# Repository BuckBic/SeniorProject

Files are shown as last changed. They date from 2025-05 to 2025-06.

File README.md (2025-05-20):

# Senior Project

# 🎓 Senior Project – Group 4

Welcome to the public repository for **Senior Project – Group 4**. This repo contains all project materials, including code, documentation, design files, and research resources. It serves as a centralized hub for development, collaboration, and public reference.

---

## 👥 Team Members

- Jeff  
- Josh  
- Valentin  
- Sean  

---

## 📁 Folder Structure

- `Documents/` – Reports, outlines, presentations, and written materials  
- `Code/` – Source code, testing scripts, and firmware  
- `Design/` – CAD models, schematics, wiring diagrams  
- `Resources/` – Data sheets, research materials, references

Folder structure may expand as the project evolves.

---

## 🎯 Purpose

- Share our work publicly for transparency and feedback  
- Collaborate as a team with version control and backups  
- Document progress across all project phases  
- Showcase our engineering and development process

---

## ✅ Usage Guidelines

- Use clear file names and keep folders organized  
- Commit regularly with concise messages  
- Don’t remove or overwrite other team members’ work without agreement  
- Keep content appropriate for public visibility

---

## 🌐 Public Access Notice

This repository is **public**. Anyone can view the content. Sensitive information or files not intended for public release should not be uploaded.

---

## 📌 Notes

If you're a reviewer, instructor, or visitor:  
All project content is located in the folders above. For questions or feedback, feel free to contact any team member directly.

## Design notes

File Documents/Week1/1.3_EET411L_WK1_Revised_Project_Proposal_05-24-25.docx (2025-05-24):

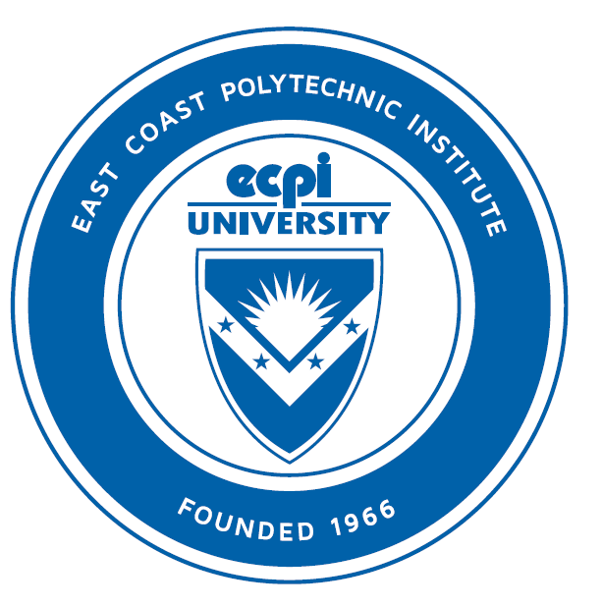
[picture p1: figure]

EET411

Senior Project

Instructor: Dr. Satinder Gill

Project Title: The Smart Bird Feeder

Team Members:

- Jeffery Wheeler: Project Lead
- Sean Copple: Team Member
- Joshua Tilson: Team Member
- Valentin Wolf: Team Member

Honor Pledge:

I pledge to support the Honor System of ECPI. I will refrain from any form of academic dishonesty or deception, such as cheating or plagiarism. I am aware that as a member of the academic community, it is my responsibility to turn in all suspected violators of the honor code. I understand that any failure on my part to support the Honor System will be turned over to a Judicial Review Board for determination. I will report to the Judicial Review Board hearing if summoned.

Date: 5/11/2025

# Abstract

This project focuses on the design and development of a smart bird feeder that improves upon existing feeders by addressing a common issue: unwanted access by animals such as raccoons. The main objective is to create a bird feeder that limits food access to birds only, using a controllable cover mechanism. The initial approach involves opening and closing the feeder based on day and night cycles. Future improvements include the integration of a load cell to detect the weight of visitors and deny access if the detected weight exceeds that of a typical bird, helping to distinguish between birds and other animals. To prevent from intruders of birds getting hurt, safety sensors are installed. The food will be supplied in small portions using a feeding wheel that is controlled by a servo motor. This mechanism ensures that the food always stays fresh.

Additional features planned include a camera for capturing images of feeding birds, a food level sensor to monitor and report when the food supply is low, and a solar panel with automatic sun tracking to power the device independently. The camera and load cell may also support bird identification and behavior analysis. The system will eventually be connected to a mobile app for live updates and alerts. The project uses a mix of sensors, automation, and app integration to enhance usability, sustainability, and data collection.

# Introduction

Bird feeding is a popular hobby that allows people to connect with nature, observe wildlife, and support local bird populations. However, many bird feeders on the market face a common problem: they are easily accessed by animals such as raccoons, squirrels, or larger pests that consume the bird food and often damage the feeder. This not only increases the cost of feeding birds but also limits the effectiveness and enjoyment of bird watching.

The main problem this project addresses is the lack of secure access control in traditional bird feeders. In many areas, especially near wooded or rural locations, raccoons and other animals frequently disrupt feeders. These intrusions reduce food availability for birds and can lead to frequent refilling and repair. While some commercial feeders offer partial solutions like baffles or weight-triggered perches, they are often not customizable, lack automation, and provide limited feedback to the user.

This project aims to design a smart bird feeder that not only prevents access by unwanted animals but also adds modern features such as automation, remote monitoring, and solar charging. By combining hardware like servo-controlled covers, load cells for weight detection, cameras, and level sensors, the feeder can intelligently respond to its environment. A mobile app will allow users to view bird photos, receive alerts about low food levels, and monitor feeder activity.

The goal of this project is to build a functional prototype of a smart bird feeder that solves the problem of animal intrusion while offering additional features to enhance the bird feeding experience. The project also explores ways to make the system energy-efficient and autonomous by incorporating solar power. Through this work, the team hopes to provide an innovative, practical solution for bird lovers and hobbyists.

# System Design

Block Diagram Overview

Power Input:

- The system is powered by a 5V 500mA solar cell.
- It collects energy from the sun to charge the batteries and run the system.

Power Management:

- The 5V relay protects the circuit and manages the power flow.
- The TP4056 charging module charges two 18650 lithium-ion batteries while allowing load sharing to avoid system shutdown during charging.
- The MT3608 boost converter steps up the battery voltage to a stable 5V output.
- A cooling system will be included to help manage heat from the charging process.

System Controller:

- A Raspberry Pi Zero is used to control the entire system.
- It processes sensor data, controls motors and LEDs, and handles any wireless communication or image capture if the camera is installed.

Field Devices:

- Servos:
  - 28BYJ-48 stepper motor rotates the bird feeder container.
  - SG90 micro servos are used for the food protection gate and solar tracking on two axes.
- Sensors:
  - Four photocell resistors detect ambient light for solar tracking and day/night detection.
  - A 1–20kg load cell with an amplifier monitors bird weight to determine if an animal is too heavy.
  - A photoresistor or IR sensor setup is used to detect when the food level is low.
- Optional Camera and Wireless Module:
  - The ESP32-CAM module adds the ability to take pictures of birds and send data wirelessly.
- RGB Status LED:
  - Used to show system status like low battery, low food, or normal operation.

Key Design Decisions and Considerations

- Solar Power: The use of a solar panel combined with load-sharing circuitry ensures that the bird feeder can operate independently of any external power sources.
- Energy Efficiency: The system limits power use at night by turning off non-essential devices like the camera and solar trackers when sunlight is not available.
- Animal Detection: The load cell allows the system to distinguish between birds and larger animals like raccoons, helping to protect the bird food.
- Weather Protection: All electronics are housed in a custom-printed, weatherproof enclosure to withstand outdoor conditions.
- Expandability: The design allows for future upgrades, such as sending bird photos through Wi-Fi or Bluetooth using the ESP32-CAM.

Block Diagram 1

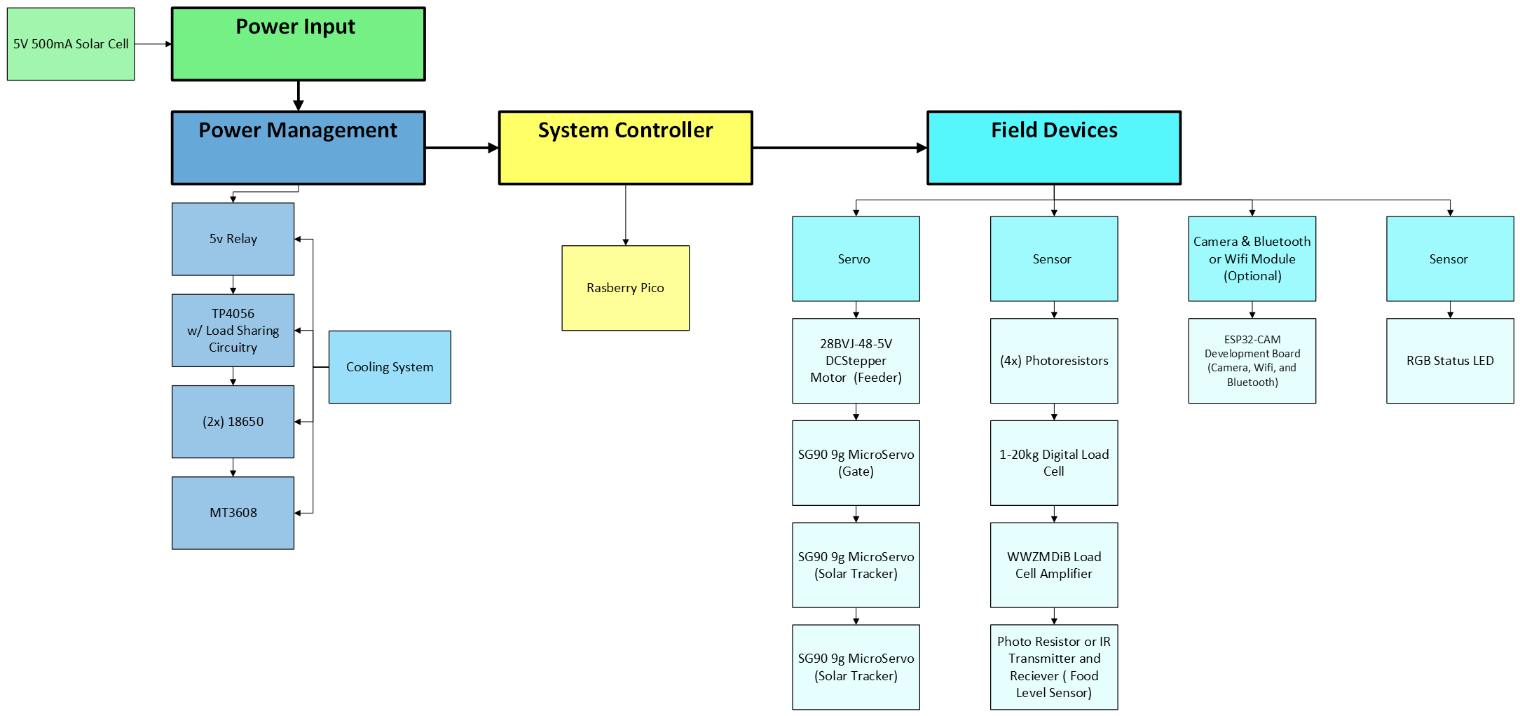
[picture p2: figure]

## Hardware Description

The smart bird feeder project uses a combination of commercially available hardware and custom-designed parts to achieve its goals. Each component was selected based on performance, availability, and compatibility with the system requirements.

Microcontrollers

- Raspberry Pi Zero The Raspberry Pi Zero is the main system controller. It manages data from the sensors, controls the field devices, and handles communication tasks such as Wi-Fi and Bluetooth.
  - Specifications: 1GHz single-core CPU, 512MB RAM, Wi-Fi, Bluetooth, mini HDMI, micro USB ports.
  - Selection Justification: Chosen for its compact size, low power consumption, and ability to handle more complex processing tasks like camera image handling and wireless communication. The Raspberry Pi Zero uses Python programming language which will be more suitable for more complex tasks.

Sensors

- Photoresistors Four photocell resistors are used to detect ambient light. They help determine day/night conditions for opening or closing the feeder and support solar tracking.
  - Selection Justification: Simple, low-cost, and reliable for detecting light changes.
- Load Cell with Amplifier (1–20kg range + HX711 amplifier) The load cell measures the weight of birds or animals at the feeder. It is sensitive enough to differentiate between birds and larger unwanted animals.
  - Selection Justification: Wide measurement range with good resolution. The amplifier boosts the small signal from the load cell to a readable level for the microcontrollers.
- Infrared Transmitter and Receiver / Photocell Food Sensor This sensor setup detects when the food level drops below a certain threshold inside the feeder.
  - Selection Justification: Simple solution to monitor food levels without requiring complex electronics.

Actuators

- SG90 9g Micro Servo Motors (4 units) Used for various mechanical movements:
  - One for rotating the food container.
  - One for opening and closing the food protection gate.
  - Two for tracking the solar panel in two axes (horizontal and vertical).
  - Specifications: 4.8V–6V operating voltage
  - Selection Justification: Lightweight, affordable, and widely supported by Arduino and Raspberry Pi libraries.
- 28BYJ-48 Stepper Motor with ULN2003 Driver Considered for smooth and accurate rotational control of the feeder.

Other Hardware Components

- 5V 500mA Solar Panel Provides renewable energy for battery charging, ensuring off-grid operation.
- TP4056 Charging Module with Load Sharing Circuit Manages safe charging of the batteries while allowing the system to continue running during charge cycles.
- 18650 Lithium-Ion Batteries (2 units) Store energy collected from the solar panel. Connected in parallel for longer runtime with 5000mAh combined capacity.
- MT3608 Boost Converter Increases the battery voltage up to 5V needed by most components.
- RGB Status LED Used to visually indicate different system statuses, such as food low, battery low, or normal operation.
- ESP32-CAM Module

Adds a camera, Wi-Fi, and Bluetooth capabilities to the system.

Custom-Designed Hardware Elements

- Feeder Mechanism: A rotating food container divided into four pockets, dispensing food every 90 degrees of rotation.
- Custom Base: Designed to securely hold all circuit boards and field devices inside a weatherproof enclosure.
- Solar Tracker Mount: A mechanical base built to allow the solar panel to rotate and track the sun for better charging efficiency.
- Load Cell Mounting Structure: Custom mounting for the load cell to ensure accurate and protected weight measurements.
- Bird Perch and Food Access Door: A landing perch for birds and a servo-controlled door that opens or closes to allow access to food based on sensor inputs.
- Acrylic Food Container: A tube that stores the bird food and makes it easy to check food levels visually.

## Software Description

The software for the smart bird feeder is still being developed. Right now, the goal is to create a simple program that controls the motors, sensors, and lights based on sensor readings.

The software will have three basic parts:

- Setup: Turn on and prepare all the parts like sensors, servos, and lights.
- Main Loop: Keep checking the sensors and make the feeder open or close based on the readings.
- Power Saving: Turn off parts of the system at night to save battery power.

Functions the Software Will Perform

- Open the food cover when it is daytime.
- Close the food cover when it is dark or when a heavy animal is detected.
- Turn on a light if food is running low.
- Move the solar panel to follow the sun (solar tracker).
- (Later) Take pictures of birds and send them over Wi-Fi.

Libraries and Tools Used

- PyCharm and micro python IDE for writing and loading the programs.
- Servo Library for moving the servo motors.
- ESP32-CAM Library (later) for taking pictures and sending them.

# Implementation & Testing

The implementation process for the smart bird feeder project started with designing and preparing the mechanical and electrical systems separately. This helped make sure that each part would fit and work correctly before full assembly.

System assembly and hardware integration

The mechanical structure of the bird feeder is being designed to be fully 3D printed. Special attention was given to leave enough space for all electrical components, as well as any future upgrades. Once the mechanical parts are finished, they are tested without any electronics installed to make sure everything fits and moves correctly. After the mechanical testing is complete, the electrical components like the Raspberry Pi, servos, sensors, and solar panel will be installed. The system will be assembled carefully to protect the wiring and to make sure that all parts are easy to access if repairs or upgrades are needed later.

Software development and debugging

The software development is done using simulation tools. Because many of the components were not available in Tinkercad, Wokwi was used to model and test the system. Debugging will continue as real components are installed, with special focus on testing the servo movements, sensor readings, and communication between parts.

Testing procedures and verification methods

Different parts of the system will be tested individually first:

- Solar Cells: Tested outside during daylight to check charging performance.
- Photosensors (Light Sensors): Tested outside to verify they correctly detect day and night conditions.
- Load Cell: Will be tested by placing different weights to make sure the readings match expected values.
- Food Level Sensor: Will be tested by adjusting food levels and checking if the sensor triggers correctly.
- Servos: Movements will be tested manually to ensure they open and close the gate properly and rotate the solar panel.
- Food dispenser will be tested first without and then with use of the stepper motor.

Once each part is tested, the full system will be tested as a whole, simulating real use by placing weights, blocking light, and adjusting food levels.

Challenges and implemented solutions

One challenge was designing the mechanical structure to fit all components while still keeping the feeder small and good-looking. Careful planning of the 3D-printed parts and early mechanical testing helped solve this issue. Another challenge was the limitation of only having three analog inputs. Temperature could also become a concern. Different 3D printing materials and colors are considered because some materials may warp or weaken in outdoor heat. Furthermore, it will be important to choose a printing material that is environmentally friendly and not harmful to the birds or other animals.

## Construction

The construction process for the smart bird feeder focuses on building strong mechanical parts, preparing for electrical integration, and testing subsystems before final assembly.

Fabrication Methods and Materials Used

Most of the mechanical components for the feeder are 3D printed. Using 3D printing allows the team to quickly create parts, test different designs, and adjust as needed.

Prototyping and Final Product Construction Process

Multiple mechanical prototypes are being made to make sure all electrical components fit properly. Since the final list of electronic parts might change, the design allows extra space for possible future upgrades.

The team divided the system into smaller sections to make testing easier. Subsystems like the solar tracker, food dispensing gate, and load cell assembly are built and tested separately. Once each subsystem works correctly, they will all be combined into one complete system.

Calibration and Fine-Tuning Steps

After assembling the full system, calibration and fine-tuning will be done. The servos will be adjusted to make sure they open and close the gates correctly. The load cell will be calibrated to measure bird weights accurately. Sensor thresholds, such as light levels for opening the gate, will be adjusted based on real outdoor testing. Software fine-tuning will also happen after full system assembly to make sure that all parts work together smoothly.

## Testing Process

The testing process for the smart bird feeder project includes a variety of tests to make sure that all functions work correctly, and that the system can survive outdoor conditions. Testing is being done step-by-step as the project is developed and assembled.

Comprehensive Testing Process

Testing is being performed on both mechanical and electrical systems. The motors, sensors, and software are tested to make sure they respond properly to different conditions. 3D printed parts are tested for correct fit, durability, and weather resistance. Electrical testing includes checking that the power system supplies enough energy and that sensor data is accurate.

Mechanical movements, waterproofing, and cooling of the electronics are also part of the testing process. The system is tested first in small parts and then as a complete unit once everything is installed.

Test Cases

Test Case 1: CAD Design and 3D Printing Test

Parts are tested after printing to make sure everything fits correctly without interference.

Test Case 2: Virtual Testing with WOKWI

Component connections and code are tested virtually using WOKWI to find problems early before installing real hardware.

Test Case 3: Hands-on Component Testing

Real components are wired together and tested using a multimeter, checking sensor readings and making sure motors move correctly.

Test Case 4: Overtemperature Prevention

The system is tested by varying the temperature around it to check if the cooling system, including fans and thermistors, keeps the electronics from overheating.

Test Case 5: Water Resistance Test

The case is sprayed with water while using water test strips inside to check for any leaks.

Test Case 6: Material Sunlight Resistance

Different 3D printed materials are exposed to sunlight to see how well they resist warping or becoming brittle.

Test Case 7: Weather Condition Testing

The feeder is tested under simulated heavy rain and wind conditions to check stability and water resistance.

Test Case 8: Environmental Material Testing

Different materials are tested to find out which ones last the longest in outdoor conditions while being environmentally friendly.

# Data Interpretation & Analysis

- Present and analyze the data collected during testing and project operation.
  - The data collected during the testing phases included values such as the overall mechanical measurements and how things would fit together after 3D printing, as well as circuit component compatibility and their operations defined by the code in microPython. Most components were originally based on one thing like the size of the pico and how many ports it had along with the power requirements. This lead to what kind of motors to use, the batteries, solar cell size and the relay for it, how much light triggers detection, and what weight to sense for a certain bird.
  - Raw Data:
    - Project Size: 4 inches Wide x 2 feet Tall
    - Bird Weight: 600 grams
    - Light Detection from ADC: 800
    - System Power requirements: 5V, 2 Amps
    - Charging requirements: 5V, 600 milliamps
    - Motor uses: Uln2003 driver, stepper, and 3x, 9-gram servos
    - IR Sensor Distance: 0.5 inches
- Discuss the meaning and implications of the obtained results.
  - Due to some of the results in the initial design, parts had to be redesigned in CAD to make sure they fit correctly and fixed some of the issues that occurred like the feeder bowl shape, component placement, and mechanical joints for both the lid and solar tracker. In addition, the Raspberry Pico only contained 3 analog to digital converters which forced us to use a digital light detecting resistor rather than simply using a photoresistor. This occurred again when trying to use the servo to rotate 360 degrees, because it can only move 180 degrees, meaning the uln2003 had to be implemented to work with the Raspberry Pico, driver a stepper motor. Lastly, the TP4056 charger would trigger overcurrent protection through its outputs, requiring the MT3608 to be connected directly to the lithium-ion batteries instead of through the charger’s output.
- Compare your results with theoretical expectations and existing research.
  - We expected not to get the results we were looking for in the first trials because it is difficult to do so on the first try. So constant adaptations of the project slowly developed though the month, resulting in major changes while maintaining the original idea. Online there are research documents on building similar products, however they do not fully imitate the work we wanted to do. Other feeders dispense food or have a camera, but do not offer solar rechargeability, food protection, or AI imaging assistance. Fewer others even used a Raspberry Pico on such a small scale so much of the final collected data like the physical measurements, working circuit, and code was done overtime as we figured out what worked and what didn’t.

# Conclusion

- Summarize the key findings and achievements of your project.
  - Few parts needed to be modified to work well with each other such as the physical dimensions, circuit connections, and code requirements.
  - Product size is needed to withstand the bird, other animals, contain components, and actuate without resistance.
  - Sensors must be within researched values like bird weight, light intensity, detection distances, and power requirements.
  - Power system needed to charge and discharge at proper voltages and current while also having a long working life.
- Restate the project objectives and evaluate their fulfillment.
  - The project objectives are to have a bird feeder that can dispense food to the correct bird based on weight, during the day only. It will be able to connect to Wi-Fi, track the sun, detect bird species, and sense when the bowl or the storage container is empty.
- Discuss the overall success of your project and its limitations.
  - Currently we have been very successful in creating a working product, however it is not assembled yet and still requires three more components to be implemented before its completion. The limitation for this system is feeding crows and keeping out other scavengers. With small changes in the design though, it can be used to feed other animals, charge a larger battery with MPPT, or be utilized in a factory to dispense other materials while keeping track of specific variables.

# Future Work

At this stage, the overall design remains consistent with our original plan, and that’s intentional. We’re now fully engaged in the build phase, installing components, testing circuits, and verifying mechanical movements. Tasks include wiring the load cell and stepper motor, calibrating sensor inputs, and confirming servo behavior in real-world conditions. We’ve also started 3D printing parts for the enclosure and feeder mechanism, refining each iteration for better fit and function.

On the software side, we’re moving from simulations to hardware testing. The control logic is being deployed to the Raspberry Pi Pico W, and we’re actively debugging issues with servo timing, sensor thresholds, and program flow. We’ve also implemented a private GitHub repository to streamline version control and collaboration. This gives the team a centralized place to share STL files, code, and documentation without losing progress or duplicating work. As the system comes together, we’re logging pass/fail results, updating code as needed, and preparing for full system integration and testing.

Looking ahead, there are still several features we plan to implement as time allows. These include AI assistance for species identification, a camera module, a more efficient cooling system, and an automated food level sensor. Future research will focus on expanding wireless functionality using the ESP32 platform to stream video and potentially incorporate AI analytics alongside it.

Beyond bird feeding, this project has broader applications. Every subsystem we’ve developed, from motion control to environmental sensing, could be adapted to other fields. The design could be scaled for use in industrial automation, smart agriculture, or even low-power off-grid systems. Every part of this system was designed in CAD, wired and coded by hand, and serves as proof of our ability to integrate mechanical, electrical, and software systems into a functional, responsive device.

# References

Raspberry Pi - 28BYJ-48 Stepper Motor ULN2003 Driver | Tutorials for Newbies. (n.d.). Tutorials for Newbies.

https://newbiely.com/tutorials/raspberry-pi/raspberry-pi-28byj-48-stepper-motor-uln2003-driver

Feeder.ino copy - Wokwi ESP32, STM32, Arduino Simulator. (n.d.).

https://wokwi.com/projects/429368894967044097

https://docs.arduino.cc/learn/electronics/servo-motorsLinks to an external site.

https://forum.allaboutcircuits.com/threads/charge-two-18650-using-single-tp4056.183851Links to an external site.

https://www.best-microcontroller-projects.com/tp4056.htmlLinks to an external site.

https://forum.arduino.cc/t/18650-battery-shield-operation-and-modification/688048/6Links to an external site.

https://m.youtube.com/watch?v=wMtaWqGTlP4

# Appendices

## Appendix A: Block Diagram

Block Diagram 1

## Appendix B: Trade Study

Trade Study 1: Animal Identification Method (Jeffery Wheeler)

Jeffery compared three options to distinguish birds from other animals: a contact sensor, an AI model with a camera, and a load cell. After reviewing accuracy, compatibility, cost, and power needs, the load cell was selected. It offers a good balance of accuracy and low power use, fits well with the system, and can be easily integrated into the perch design.

Trade Study 2: Microcontroller Selection (Sean Copple)

Sean evaluated the Arduino Uno, Raspberry Pi Zero 2 W, and Raspberry Pi Pico W for controlling the smart bird feeder. The Raspberry Pi Pico W was selected because it has strong wireless capability, good GPIO support for sensors and motors, a small size for the case, and better power efficiency. It also allows faster software development.

Trade Study 3: Servo Motor Selection for Food Gate (Valentin Wolf)

Valentin compared three servo motors: the SG90, MG90S, and DS3218. Although the MG90S is stronger and better for outdoor use, the team already owns SG90 servos. The plan is to first test the SG90. If it does not provide enough torque, the MG90S will be used as a backup.

Trade Study 4: Boost converter selection (Josh Tilson)

Josh evaluated the boost converter to output more current for the system. His three choices were between MT3608, XL6009, and XL6019. At first the MT3608 was chosen because it was a cheaper well-known option which still works in the circuit now. However, it has a limitation of 2 amps which could be overdrawn if all components are working at the same time. It is unlikely that it will take more than 2 amps during its operation, but if more current is required the XL6019 is a good replacement that is slightly more expensive and is capable of 5 amps instead.

## Appendix C: Budget

### Budget

The Budget for this project is about 150 Dollars for the major components of the Bird feeder.

### Parts List

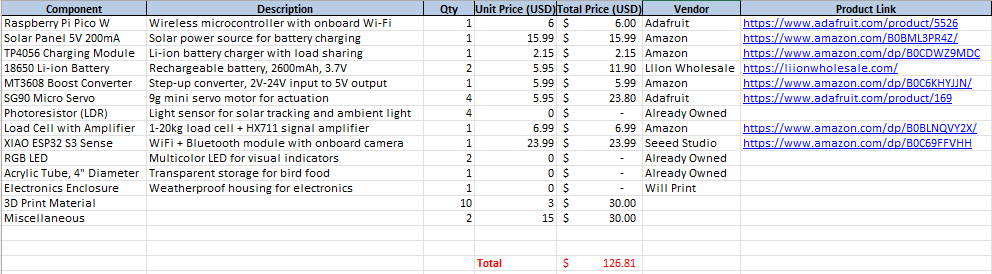
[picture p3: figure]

### Bill of Materials (BOM)

## Appendix D: Schedule/Gantt Chart

#### Team Structure:

The project team is composed of five members: Jeffery Wheeler, Sean Copple, Joshua Tilson, and Valentin Wolf. Each member brings a unique skill set to the group, allowing for a well-rounded and collaborative approach to the smart bird feeder project. Team roles were assigned based on individual experience and personal strengths.

Jeffery Wheeler is the project lead. He initially proposed the bird feeder idea and has extensive experience in mechanical systems and control design. He also owns a 3D printer and has a clear vision for the final product’s design and functionality. As the team lead, he will guide the project’s direction, coordinate tasks, and make final decisions when needed.

Sean Copple is highly skilled in both electrical and mechanical tasks and also owns a 3D printer. Sean is responsible for identifying and sourcing critical hardware components and assisting with physical assembly and wiring.

Joshua Tilson is part of the Mechatronics program and brings strong experience in building control systems. Like the rest of the group, he has access to a 3D printer and is involved in selecting components for the project. Joshua will also support hardware integration and testing.

Valentin is responsible for the documentation and communication. He is responsible for writing and organizing project materials, scheduling meetings, and coordinating information flow between team members. He also supports all other areas of the project as needed.

Although specific roles have been assigned, all team members contribute across disciplines, including software, hardware, and design. Tasks are divided to maximize efficiency and are reassigned as needed based on availability and progress. All major decisions are made collectively. If any disagreement arises, the project lead will make the final decision to maintain momentum and ensure consistency.

#### Communication Plan:

Effective communication is essential for this project, especially since the team members are located in different time zones. To stay connected and on track, the team has implemented a structured communication plan with multiple tools and channels.

A dedicated group chat was created for quick updates, sharing images and videos, and staying in regular contact. For more formal discussions, the team uses the ECPI Canvas group page, which includes discussion boards for each project topic. This platform is also used for collaboration on weekly assignments and lab reports.

In addition, the team shares and updates project files through a shared folder on the ECPI group page. All files are organized by week and labeled with clear names and timestamps to track progress and maintain version control. To improve collaboration and file management, the team also implemented a GitHub repository. This has become the main hub for storing code, documentation, STL files, and design updates. GitHub allows for version control, easier syncing between members, and reduces the risk of losing progress due to file overwrites or miscommunication.

The team meets twice a week. The first meeting takes place at the beginning of the week to plan tasks and delegate responsibilities. A second meeting is held every Sunday to review the week’s progress, discuss any issues, and prepare for the next steps. These meetings are held virtually to accommodate different time zones.

This structured plan ensures that all team members are informed, involved, and able to contribute effectively throughout the five-week project.

#### Gantt Chart:

Gantt Chart

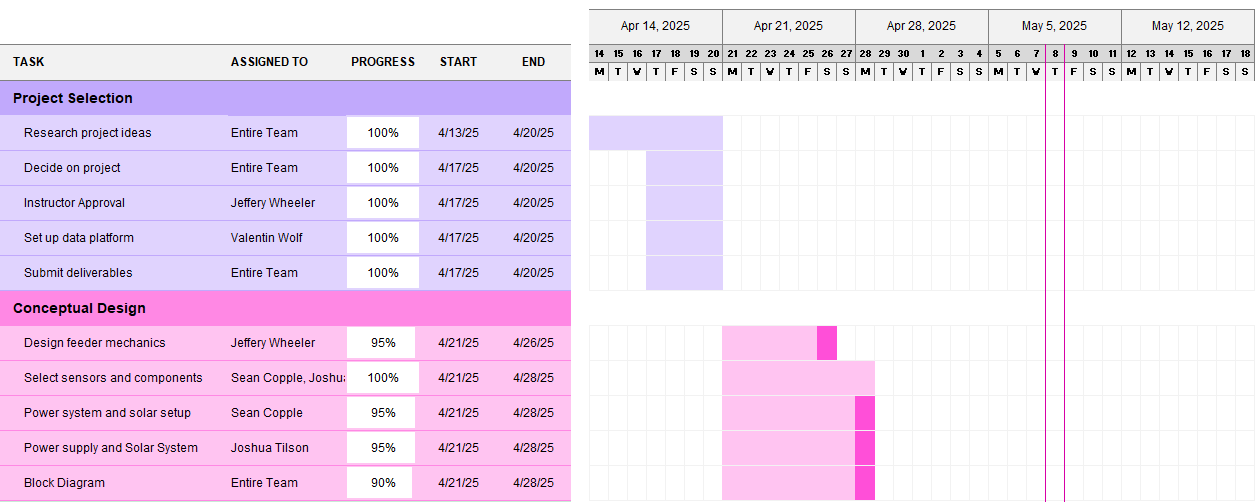
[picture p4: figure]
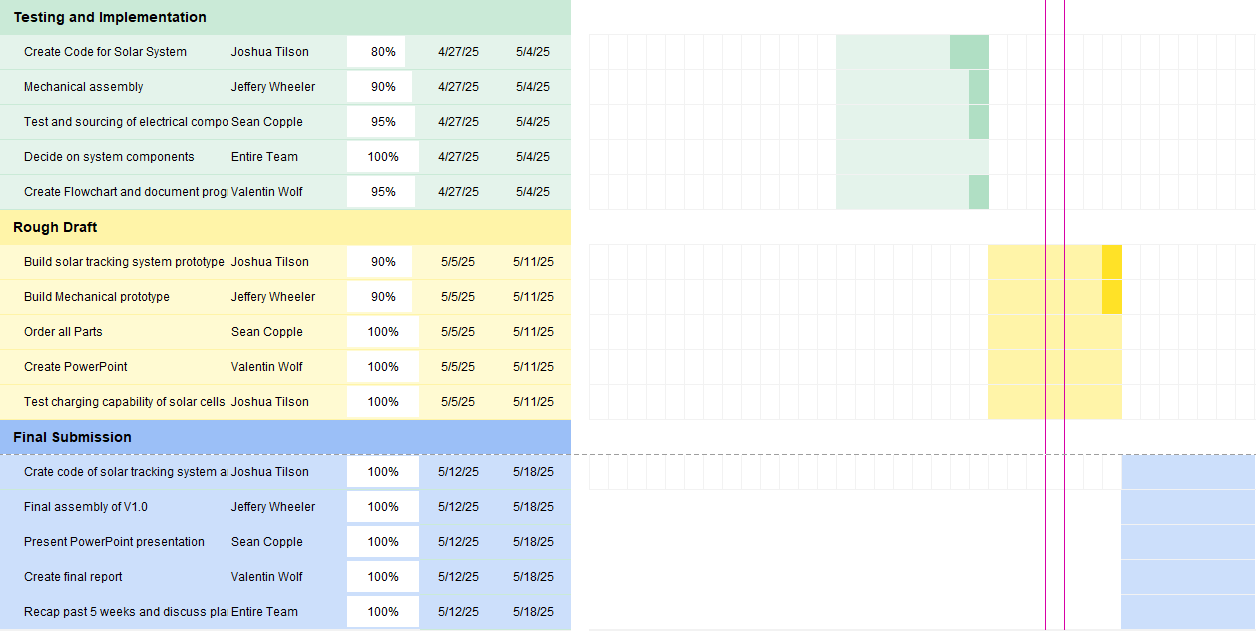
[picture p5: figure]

## Appendix E: Code

### Flowchart

Flowchart System Overview

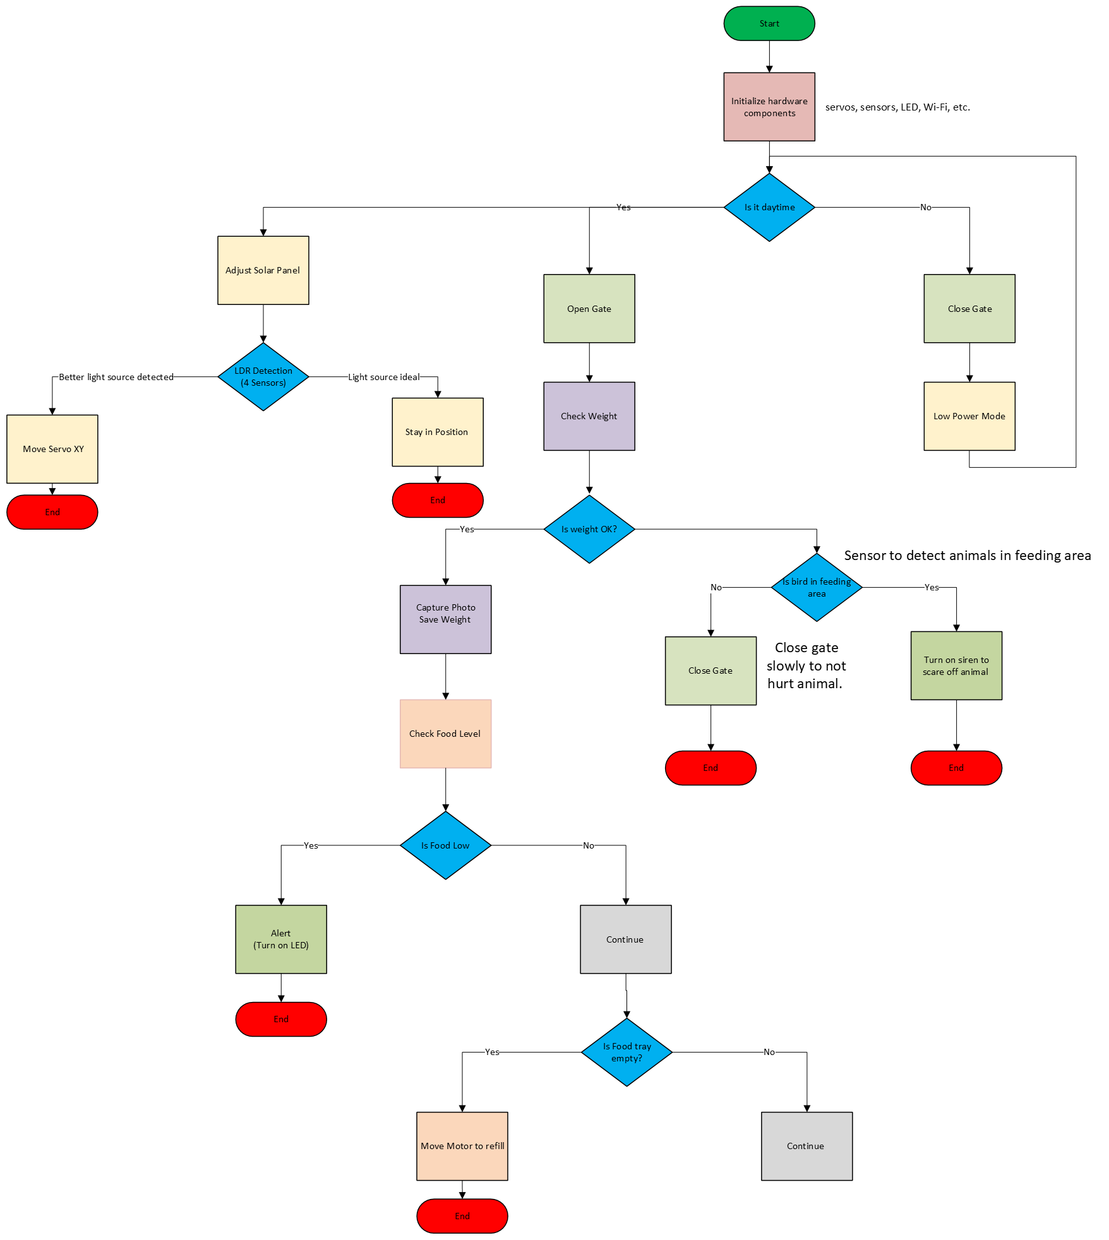
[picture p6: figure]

Code:

Feeder Section -

#from hx711_gpio1 import HX711
import time
from machine import Pin,PWM

# Constants for the stepper motor pins
IN1 = Pin(18, Pin.OUT)
IN2 = Pin(19, Pin.OUT)
IN3 = Pin(20, Pin.OUT)
IN4 = Pin(21, Pin.OUT)
IRSensor = Pin(16, Pin.IN, Pin.PULL_UP)
Photosensor = machine.ADC(28)
#data_pin = Pin(14, Pin.IN, Pin.PULL_DOWN)
#clock_pin = Pin(15, Pin.OUT)
#hx711 = HX711(clock_pin, data_pin)
#hx711.tare()
lid = PWM(Pin(2))
lid.freq(50)

# Sequence for moving the stepper motor
SEQUENCE = [[1,0,0,0], [0,1,0,0], [0,0,1,0], [0,0,0,1]]

# Function to move the stepper motor
def move_stepper(direction, steps):
# Set the input pins
pins = [IN1, IN2, IN3, IN4]

# Set the direction of the sequence
if direction == 'forward':
sequence = SEQUENCE
elif direction == 'backward':
sequence = list(reversed(SEQUENCE))

# Loop through the specified number of steps
for i in range(steps):

# Set the input pins based on the current step
for j in range(len(pins)):
pins[j].value(sequence[i%4][j])

# Delay between steps
time.sleep(0.002)

# Main loop
while True:
print(IRSensor.value())
print("ADC: ", Photosensor.read_u16())
#raw_wt = hx711.read()
#sf = 340/350000
#weight = raw_wt*sf

if (IRSensor.value() == 0 and Photosensor.read_u16() <= 800): # if bowl is empty (IR) and is daytime(photosensor)
move_stepper('forward', 512)
time.sleep(2)

if (weight.value() <= 600 and Photosensor.read_u16() <= 800): # if weight is in range and is daytime
for position in range(500000, 2500000, 5000): # open lid
lid.duty_ns(position)
time.sleep(0.01)

else:
for position in range(2500000, 500000, -5000): # close lid
lid.duty_ns(position)
time.sleep(0.01)

Solar Tracker Section -

import time
from machine import Pin,PWM
#Looking at the panel with sensors facing you
TL = Pin(3, Pin.IN) #LDR top left
TR = Pin(4, Pin.IN) #LDR top right
BL = Pin(5, Pin.IN) #LDR Bottom left
BR = Pin(6, Pin.IN) #ldr Bottom right

Xaxis = PWM(Pin(2)) # sets x and y axis servo pins as pwm signal
Yaxis = PWM(Pin(17))

Xaxis.freq(50) # sets x and y axis pwm output frequency
Yaxis.freq(50)

positionx = 1500000 # start each servo to their midpoint position in nanseconds as duty cycle
positiony = 1500000

while True: # loop section

if (TL.value() == 1 and TR.value() == 1): #if top left and top right LDR sensors reach their preset values
Yaxis.duty_ns(positiony) # move y axis servo to saved variable
positiony = positiony + 5000 # add 5000 nanoseconds to duty cycle and change the variable value
time.sleep(0.01) # wait 10 milliseconds between each step

if (TL.value() == 1 and BL.value() == 1): # same sequences as before with different sensors sets
Xaxis.duty_ns(positionx)
positionx = positionx - 5000 # negative indicates reverse direction
time.sleep(0.01)

if (BL.value() == 1 and BR.value() == 1):
Yaxis.duty_ns(positiony)
positiony = positiony - 5000
time.sleep(0.01)

if (TR.value() == 1 and BR.value() == 1):
Xaxis.duty_ns(positionx)
positionx = positionx + 5000
time.sleep(0.01)

## Appendix F: Wiring Diagrams/Parts Design

Wiring and Parts for System

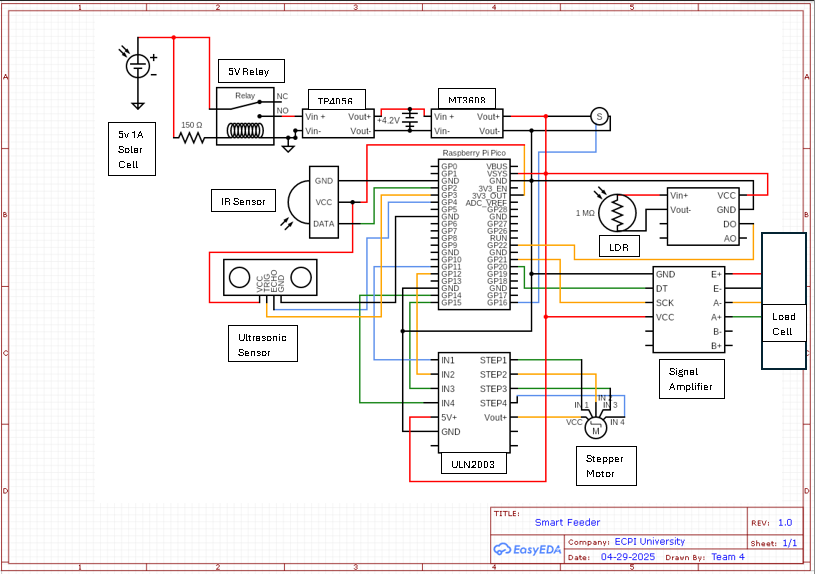
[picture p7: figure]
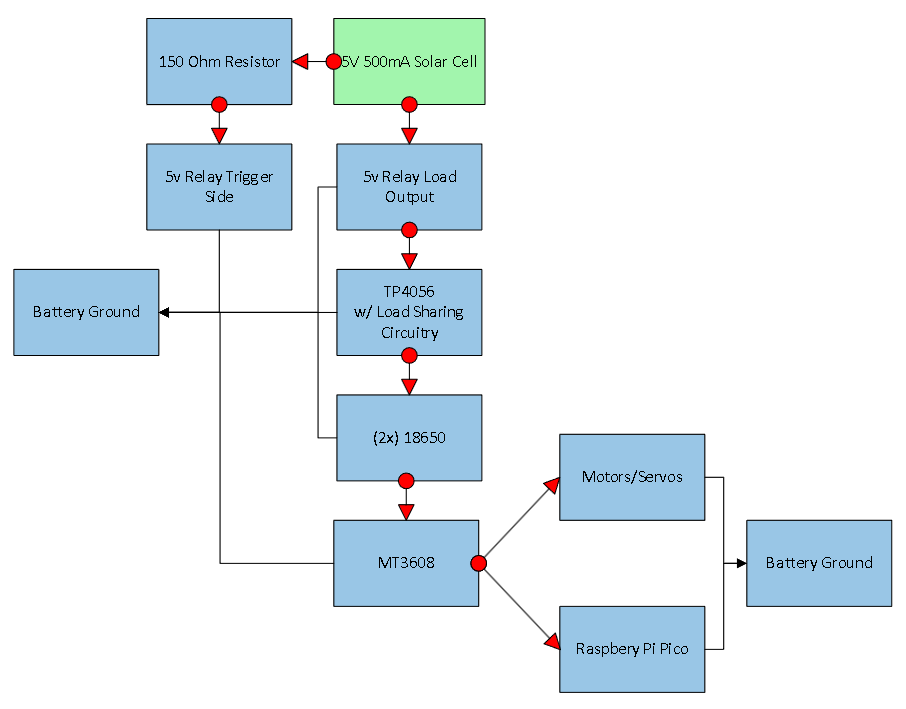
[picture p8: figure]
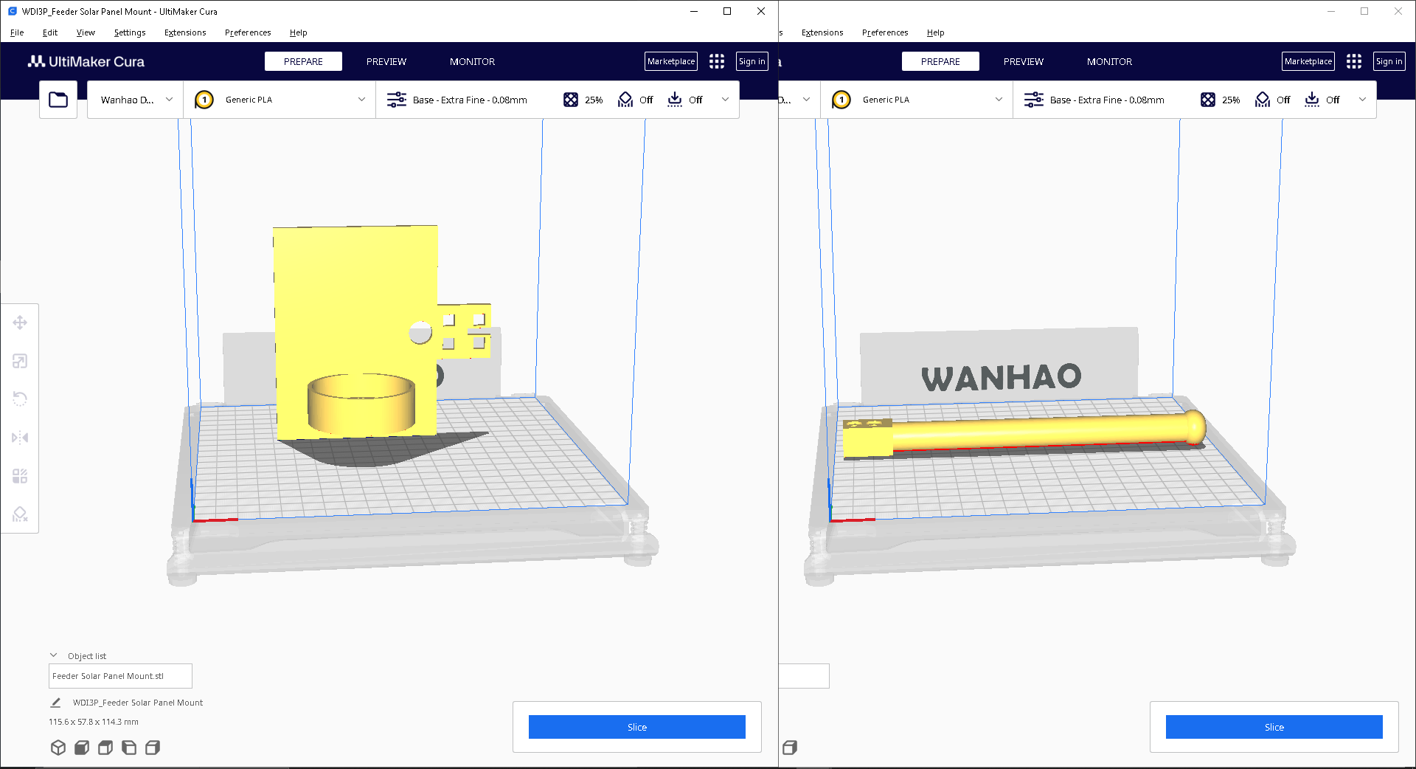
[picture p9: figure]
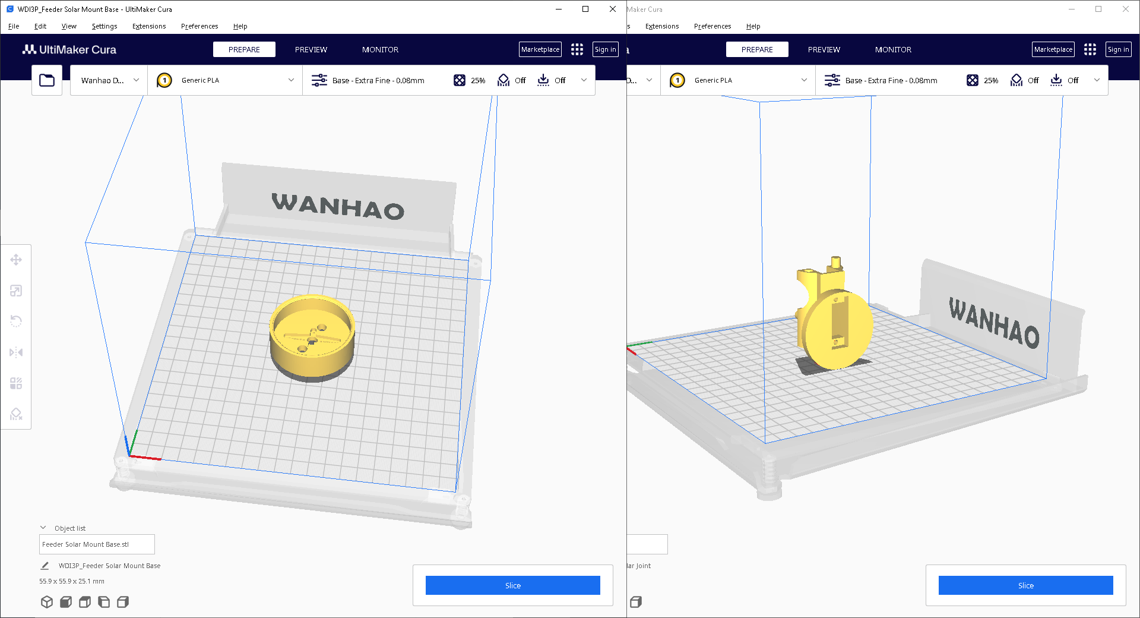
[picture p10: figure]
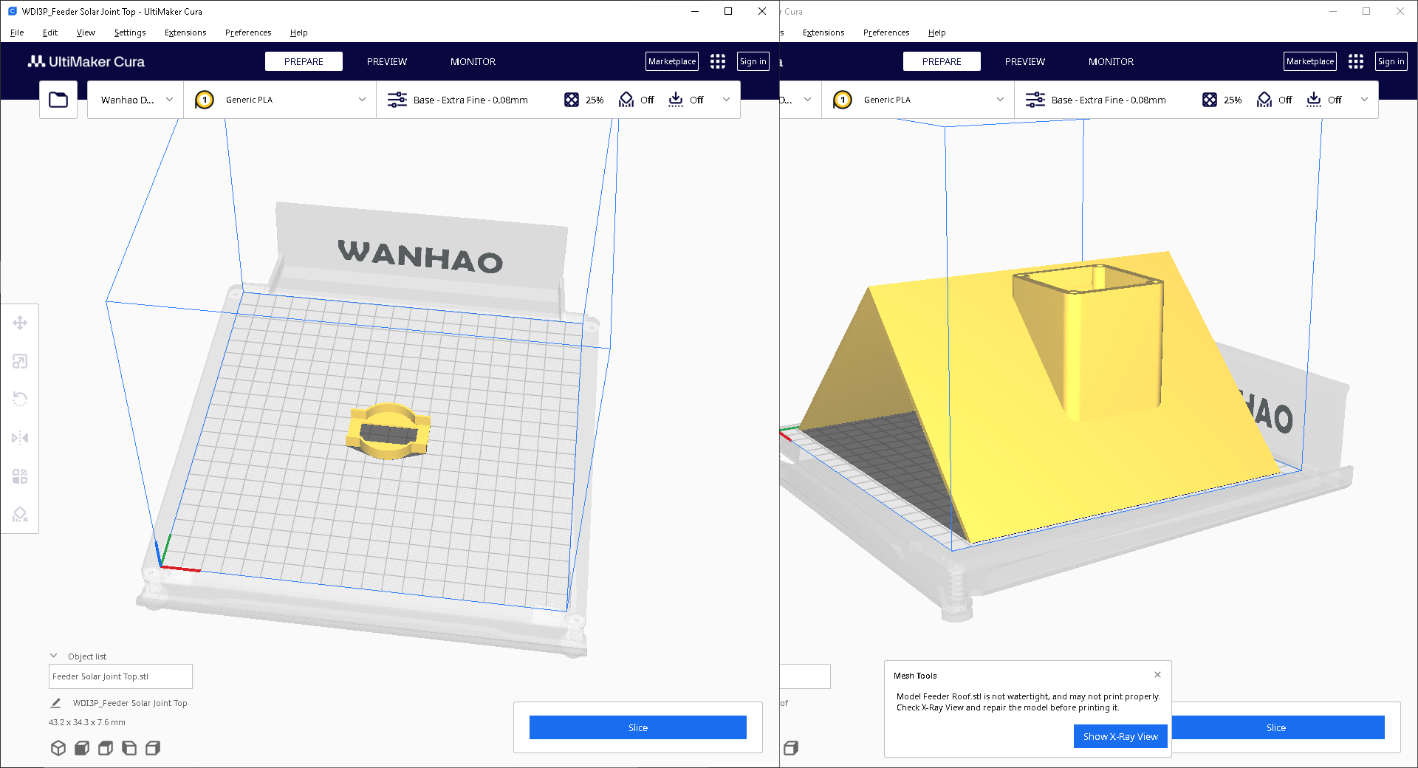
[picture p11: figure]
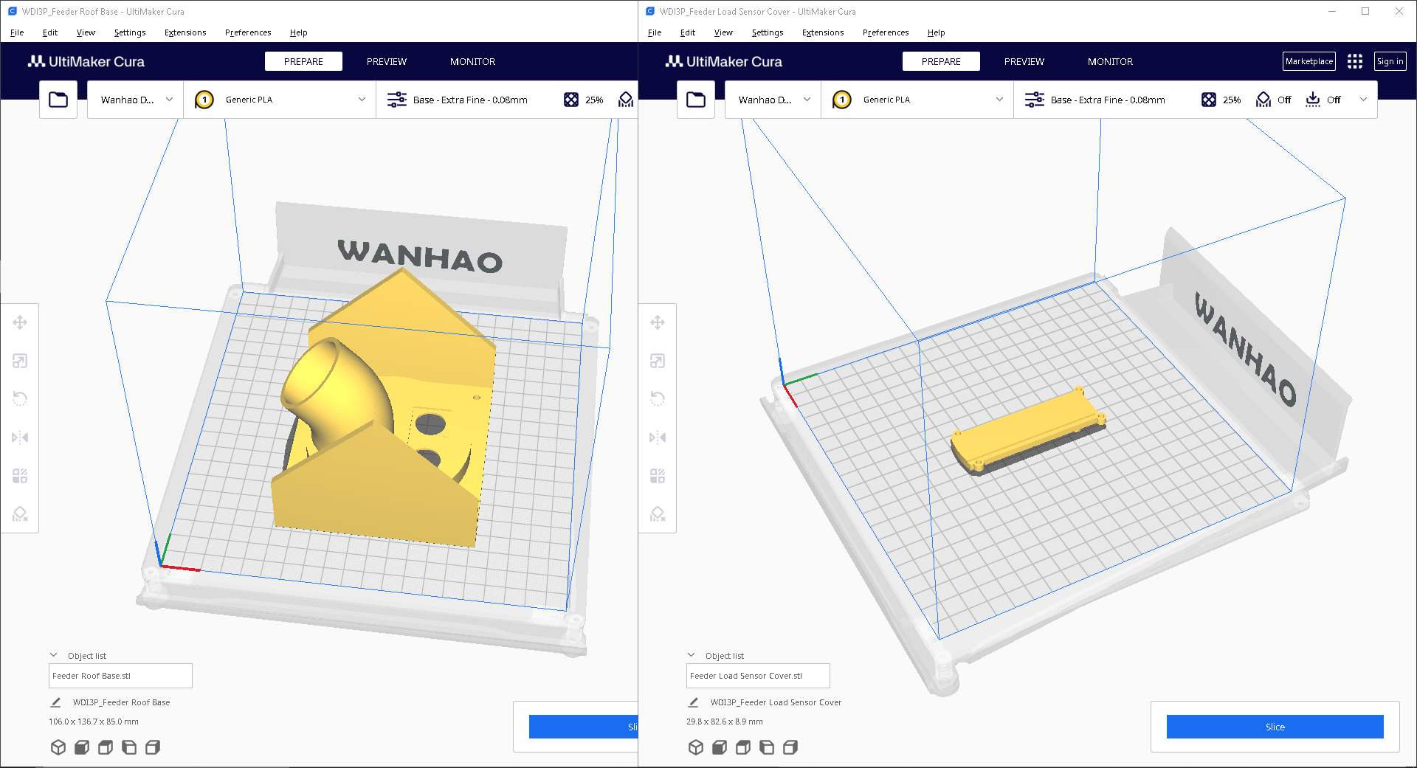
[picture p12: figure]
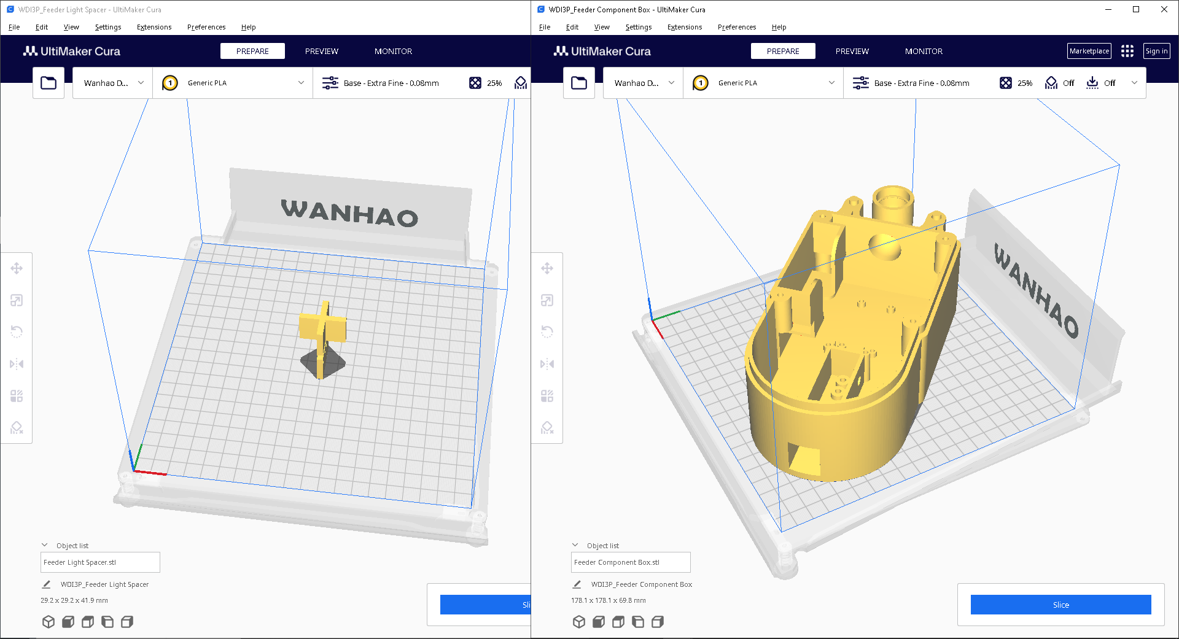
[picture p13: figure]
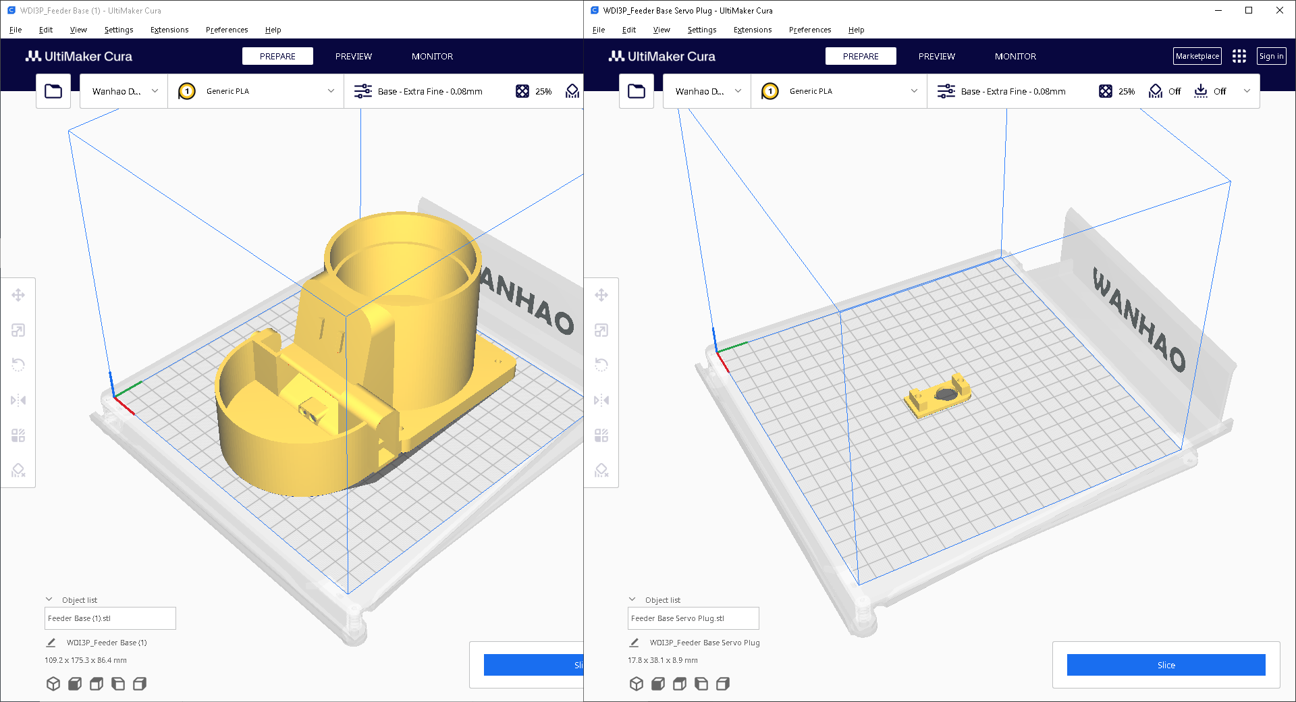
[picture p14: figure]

School of Engineering Technology

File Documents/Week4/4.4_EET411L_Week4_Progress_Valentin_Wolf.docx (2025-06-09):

# Progress Report

Week 4 | | | 6/8/2025
Group Members | | Jeffery Wheeler
| | Joshua Tilson
| | Sean Copple
| | Valentin Wolf
Project Title | | The Smart Bird Feeder

## Task: Mechanical Prototype Assembly

Task Status: In Progress | | | 90% Completed: | | | Jeffery Wheeler
Task Details

Completed full 3D print of version 1 feeder housing. All parts were assembled to test physical fit of electrical components. Next step is to perform functional testing with electronics installed.

Modifications were made to the bracket that holds the bird feeder. The new version is able to hold more weight.

A change was made to the mechanical design to allow easy access to a USB cable. This change makes it easier to access for program updates
Conclusions

All mechanical parts fit correctly, and layout is confirmed. Further testing is required to check motion, access, and cable routing before finalizing version 2 design.
Action items | | | | | Person responsible | | Deadline
Begin full system testing inside housing | | | | | Jeffery Wheeler | | 6/10/2025
Prepare feedback on version 1 for version 2 improvements | | | | | Jeffery Wheeler | | 6/01/2025
Assemble full prototype | | | | | Jeffery Wheeler | | 6/10/2025

Task: Component Integration Testing
Task Status: In Progress | | | 100% Completed: | | | Joshua Tilson
Task Details

All sensors and motor components were connected on a test bench. Ongoing tests are running to confirm proper integration between power supply, load cell, servo, and sensors.

All major components function in initial test setup.
Conclusions

Initial integration looks good. Power and sensor response are stable. Some minor adjustments to wiring and code structure are expected as testing continues.

Code was further optimized to adjust speed of servo motors effectively
Action items | | | | | Person responsible | | Deadline
Finish component testing with all sensors active | | | | | Joshua Tilson | | 6/07/2025
Log any errors or unexpected behaviors during tests | | | | | Joshua Tilson | | 6/07/2025
Combine code for all subsystems | | | | | Joshua Tilson | | 6/07/2025

## Task: GitHub Code & File Sharing Setup

Task Status: In Progress | | | 100% Completed: | | | Sean Copple
Task Details

Created a new shared GitHub repository to improve team collaboration. Includes release notes, shared code access, and expanded storage for print files.

Github was updated and all team members were trained on how to use the platform effectively
Conclusions

The new system allows real-time updates and easier code review. It also supports file versioning and notes to reduce confusion and track changes.

The new platform shows great improvement in communication.

Code was converted from individual files to .py files.

Function to test code in Github was activated
Action items | | | | | Person responsible | | Deadline
Share login and usage instructions with team | | | | | Sean Copple | | 5/31/2025
Use GitHub for all future code versions and STL file uploads | | | | | Sean Copple | | 5/31/2025
Organize files and information on Github | | | | | Sean Copple | | 6/01/2025

## Task: Solar Tracking System

Task Status: In Progress | | 90% Completed: | | Joshua Tilson
Task Details

Assemble and test the solar tracking system using light-dependent resistors (LDRs) and servo motors. The parts are currently being 3D printed and put together to check boundaries, avoid collisions, and ensure the solar panel adjusts its position based on actual sunlight. Final testing will be done outdoors.
Conclusions

Initial movement testing has been successful. Further testing with real sunlight is needed to confirm tracking accuracy. Once the Mosfet arrives, full system testing with charging and current delivery will be completed.
Action items | | | Person responsible | | Deadline
Test solar tracker movement with sunlight | | | Joshua Tilson | | 6/01/2025
Install and test Mosfet for charging circuit | | | Joshua Tilson | | 6/10/2025

## Task: Testing and Validation

Task Status: In Progress | | 80% Completed: | | Valentin Wolf
Task Details

Created the Testing and Validation section for the project report. This included developing a test plan for each subsystem, writing test case descriptions, pass/fail results, and brief analysis of each outcome. Real testing input from team members was reviewed and integrated into the documentation.
Conclusions

The testing tasks have been defined and the testing is in progress.

Test results have been recorded and summarized
Action items | | | Person responsible | | Deadline
Complete all tests and report results | | | Valentin Wolf | | 6/10/2025
Document all final tests | | | Valentin Wolf | | 6/10/2025

School of Technology 2025

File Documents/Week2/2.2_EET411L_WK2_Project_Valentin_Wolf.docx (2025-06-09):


EET411L

Senior Project

Instructor: Dr. Satinder Gill

Project Title: The Smart Bird Feeder

Team Members:

- Jeffery Wheeler: Project Lead
- Sean Copple: Team Member
- Joshua Tilson: Team Member
- Valentin Wolf: Team Member

Honor Pledge:

I pledge to support the Honor System of ECPI. I will refrain from any form of academic dishonesty or deception, such as cheating or plagiarism. I am aware that as a member of the academic community, it is my responsibility to turn in all suspected violators of the honor code. I understand that any failure on my part to support the Honor System will be turned over to a Judicial Review Board for determination. I will report to the Judicial Review Board hearing if summoned.

Date: 5/25/2025

# Abstract - Updated

This project focuses on the design and development of a smart bird feeder that improves upon existing feeders by addressing a common issue: unwanted access by animals such as raccoons. The main objective is to create a bird feeder that limits food access to birds only, using a controllable cover mechanism. The initial approach involves opening and closing the feeder based on day and night cycles. Future improvements include the integration of a load cell to detect the weight of visitors and deny access if the detected weight exceeds that of a typical bird, helping to distinguish between birds and other animals. To prevent birds from being harmed by moving parts, safety sensors are installed. The food will be supplied in small portions using a feeding wheel controlled by a servo motor. This mechanism ensures that the food always stays fresh.

Additional features planned include a food level sensor to monitor and report when the food supply is low, and a solar panel with automatic sun tracking to power the device independently. While the camera is no longer part of the main feeder system, it may still be added later as a separate module, such as an adjustable arm that can be mounted nearby to capture images of feeding birds. The system uses a mix of sensors, automation, and modular expansion to improve usability, sustainability, and potential for future data collection.

# Introduction - Updated

Bird feeding is a popular hobby that allows people to connect with nature, observe wildlife, and support local bird populations. However, many bird feeders on the market face a common problem: they are easily accessed by animals such as raccoons, squirrels, or other larger pests that consume the bird food and often damage the feeder. This not only increases the cost of feeding birds but also limits the effectiveness and enjoyment of bird watching.

The main problem this project addresses is the lack of secure access control in traditional bird feeders. In many areas, especially near wooded or rural locations, raccoons and other animals frequently disrupt feeders. These intrusions reduce food availability for birds and can lead to frequent refilling and repairs. While some commercial feeders offer partial solutions like baffles or weight-triggered perches, they are often not customizable, lack automation, and provide limited feedback to the user.

This project aims to design a smart bird feeder that not only prevents access by unwanted animals but also adds modern features such as automation, smart sensing, and solar charging. By combining hardware like servo-controlled covers, load cells for weight detection, and food level sensors, the feeder can respond intelligently to its environment. A mobile app is planned for future development to provide users with alerts about food levels and basic system updates.

Although a camera was originally planned, it has been removed from the initial build to reduce complexity. However, a separate module - such as an external camera mounted on an adjustable arm -may be added later for photo capture and observation without interfering with the main system.

The goal of this project is to build a functional prototype of a smart bird feeder that solves the problem of animal intrusion while offering additional features to enhance the bird feeding experience. The project also explores how to make the system energy-efficient and autonomous by incorporating solar power. Through this work, the team hopes to provide an innovative, practical solution for bird lovers and hobbyists.

# System Design - Updated

Block Diagram Overview

Power Input:

- The system is powered by a 5V 500mA solar cell.
- It collects energy from the sun to charge the batteries and run the system.

Power Management:

- The 5V relay protects the circuit and manages the power flow.
- The TP4056 charging module charges two 18650 lithium-ion batteries while allowing load sharing to avoid system shutdown during charging.
- The MT3608 boost converter steps up the battery voltage to a stable 5V output.
- A cooling system will be included to help manage heat from the charging process.

System Controller:

- A Raspberry Pi Zero is used to control the entire system.
- It processes sensor data, controls motors and LEDs, and handles any wireless communication or image capture if the camera is installed.

Field Devices:

- Servos:
  - 28BYJ-48 stepper motor rotates the bird feeder container.
  - SG90 micro servos are used for the food protection gate and solar tracking on two axes.
- Sensors:
  - Four photocell resistors detect ambient light for solar tracking and day/night detection.
  - A 1–20kg load cell with an amplifier monitors bird weight to determine if an animal is too heavy.
  - A photoresistor or IR sensor setup is used to detect when the food level is low.
- RGB Status LED:
  - Used to show system status like low battery, low food, or normal operation.

Key Design Decisions and Considerations

- Solar Power: The use of a solar panel combined with load-sharing circuitry ensures that the bird feeder can operate independently of any external power sources.
- Energy Efficiency: The system limits power use at night by turning off non-essential devices like the camera and solar trackers when sunlight is not available.
- Animal Detection: The load cell allows the system to distinguish between birds and larger animals like raccoons, helping to protect the bird food.
- Weather Protection: All electronics are housed in a custom-printed, weatherproof enclosure to withstand outdoor conditions.
- Expandability: The design allows for future upgrades, such as sending bird photos through Wi-Fi or Bluetooth using the ESP32-CAM.

Block Diagram 1 - Updated

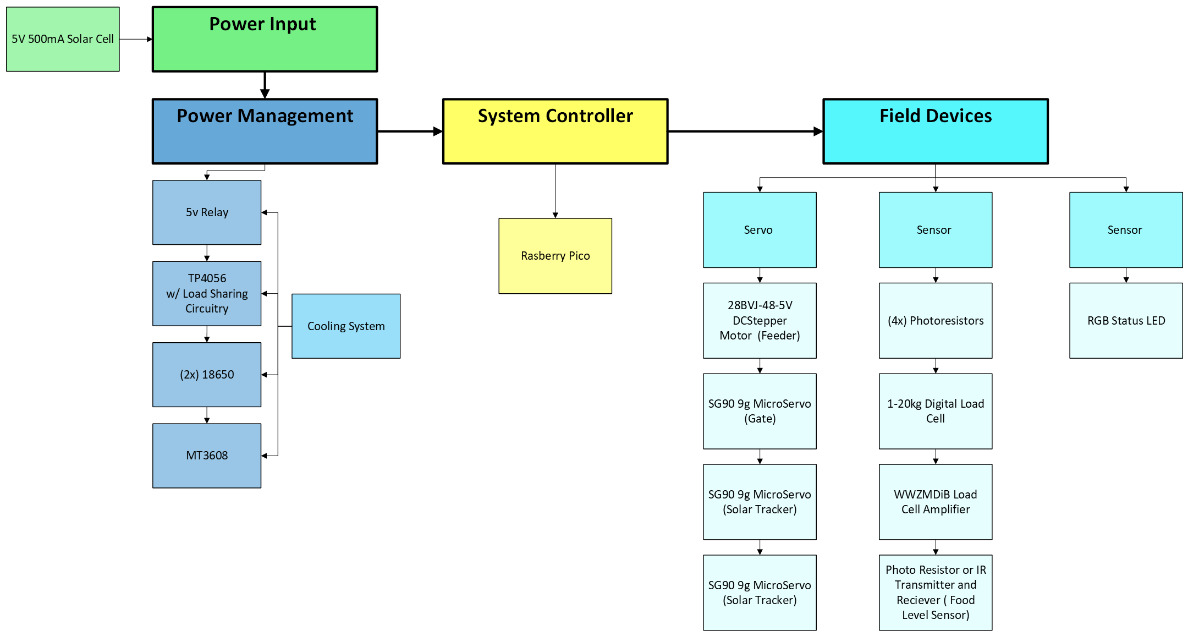
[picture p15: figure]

## Hardware Description

The smart bird feeder project uses a combination of commercially available hardware and custom-designed parts to achieve its goals. Each component was selected based on performance, availability, and compatibility with the system requirements.

Microcontrollers

- Raspberry Pi Zero The Raspberry Pi Zero is the main system controller. It manages data from the sensors, controls the field devices, and handles communication tasks such as Wi-Fi and Bluetooth.
  - Specifications: 1GHz single-core CPU, 512MB RAM, Wi-Fi, Bluetooth, mini HDMI, micro USB ports.
  - Selection Justification: Chosen for its compact size, low power consumption, and ability to handle more complex processing tasks like camera image handling and wireless communication. The Raspberry Pi Zero uses Python programming language which will be more suitable for more complex tasks.

Sensors

- Photoresistors Four photocell resistors are used to detect ambient light. They help determine day/night conditions for opening or closing the feeder and support solar tracking.
  - Selection Justification: Simple, low-cost, and reliable for detecting light changes.
- Load Cell with Amplifier (1–20kg range + HX711 amplifier) The load cell measures the weight of birds or animals at the feeder. It is sensitive enough to differentiate between birds and larger unwanted animals.
  - Selection Justification: Wide measurement range with good resolution. The amplifier boosts the small signal from the load cell to a readable level for the microcontrollers.
- Infrared Transmitter and Receiver / Photocell Food Sensor This sensor setup detects when the food level drops below a certain threshold inside the feeder.
  - Selection Justification: Simple solution to monitor food levels without requiring complex electronics.

Actuators

- SG90 9g Micro Servo Motors (4 units) Used for various mechanical movements:
  - One for rotating the food container.
  - One for opening and closing the food protection gate.
  - Two for tracking the solar panel in two axes (horizontal and vertical).
  - Specifications: 4.8V–6V operating voltage
  - Selection Justification: Lightweight, affordable, and widely supported by Arduino and Raspberry Pi libraries.
- 28BYJ-48 Stepper Motor with ULN2003 Driver Considered for smooth and accurate rotational control of the feeder.

Other Hardware Components

- 5V 500mA Solar Panel Provides renewable energy for battery charging, ensuring off-grid operation.
- TP4056 Charging Module with Load Sharing Circuit Manages safe charging of the batteries while allowing the system to continue running during charge cycles.
- 18650 Lithium-Ion Batteries (2 units) Store energy collected from the solar panel. Connected in parallel for longer runtime with 5000mAh combined capacity.
- MT3608 Boost Converter Increases the battery voltage up to 5V needed by most components.
- RGB Status LED Used to visually indicate different system statuses, such as food low, battery low, or normal operation.
- ESP32-CAM Module

Adds a camera, Wi-Fi, and Bluetooth capabilities to the system.

Custom-Designed Hardware Elements

- Feeder Mechanism: A rotating food container divided into four pockets, dispensing food every 90 degrees of rotation.
- Custom Base: Designed to securely hold all circuit boards and field devices inside a weatherproof enclosure.
- Solar Tracker Mount: A mechanical base built to allow the solar panel to rotate and track the sun for better charging efficiency.
- Load Cell Mounting Structure: Custom mounting for the load cell to ensure accurate and protected weight measurements.
- Bird Perch and Food Access Door: A landing perch for birds and a servo-controlled door that opens or closes to allow access to food based on sensor inputs.
- Acrylic Food Container: A tube that stores the bird food and makes it easy to check food levels visually.

## Software Description - Updated

The software for the smart bird feeder is still being developed. Right now, the goal is to create a simple program that controls the motors, sensors, and lights based on sensor readings.

The software will have three basic parts:

- Setup: Turn on and prepare all the parts like sensors, servos, and lights.
- Main Loop: Keep checking the sensors and make the feeder open or close based on the readings.
- Power Saving: Turn off parts of the system at night to save battery power.

Functions the Software Will Perform

- Open the food cover when it is daytime.
- Close the food cover when it is dark or when a heavy animal is detected.
- Turn on a light if food is running low.
- Move the solar panel to follow the sun (solar tracker).

Libraries and Tools Used

- PyCharm and micro python IDE for writing and loading the programs.
- Servo Library for moving the servo motors.
- ESP32-CAM Library (later) for taking pictures and sending them.

# Implementation & Testing

The implementation process for the smart bird feeder project started with designing and preparing the mechanical and electrical systems separately. This helped make sure that each part would fit and work correctly before full assembly.

System assembly and hardware integration

The mechanical structure of the bird feeder is being designed to be fully 3D printed. Special attention was given to leave enough space for all electrical components, as well as any future upgrades. Once the mechanical parts are finished, they are tested without any electronics installed to make sure everything fits and moves correctly. After the mechanical testing is complete, the electrical components like the Raspberry Pi, servos, sensors, and solar panel will be installed. The system will be assembled carefully to protect the wiring and to make sure that all parts are easy to access if repairs or upgrades are needed later.

Software development and debugging

The software development is done using simulation tools. Because many of the components were not available in Tinkercad, Wokwi was used to model and test the system. Debugging will continue as real components are installed, with special focus on testing the servo movements, sensor readings, and communication between parts.

Testing procedures and verification methods

Different parts of the system will be tested individually first:

- Solar Cells: Tested outside during daylight to check charging performance.
- Photosensors (Light Sensors): Tested outside to verify they correctly detect day and night conditions.
- Load Cell: Will be tested by placing different weights to make sure the readings match expected values.
- Food Level Sensor: Will be tested by adjusting food levels and checking if the sensor triggers correctly.
- Servos: Movements will be tested manually to ensure they open and close the gate properly and rotate the solar panel.
- Food dispenser will be tested first without and then with use of the stepper motor.

Once each part is tested, the full system will be tested as a whole, simulating real use by placing weights, blocking light, and adjusting food levels.

Challenges and implemented solutions – Updated

One challenge was designing the mechanical structure to fit all components while still keeping the feeder small and good-looking. Careful planning of the 3D-printed parts and early mechanical testing helped solve this issue. Changes were made to improve the internal layout, and the design was adjusted to make room for more reliable mounting of the electronics.

Another issue involved the battery mounting. The original plan was to place a set of tagged-together batteries into a dedicated battery box. However, during assembly, the battery box did not fit properly inside the prototype. This led to a redesign of the battery housing and the decision to use a new battery pack.

There was also a challenge with how to easily access the Raspberry Pi Pico for programming. To make updates more practical during testing and future improvements, the design was modified to allow a USB cable to be plugged in easily without having to disassemble the whole unit.

The bracket that supports the bird feeder was another area that needed improvement. The initial version was not strong enough to hold the full weight of the feeder, especially when loaded with food and electronics. It was redesigned to be more structurally stable, using stronger geometry and reinforced mounting points to prevent bending or breakage.

As of now, the solar tracker parts are being printed and assembled to test proper servo movements and ensure the panel doesn’t hit any other parts during rotation. The goal is to test how it behaves under real sunlight rather than artificial lighting. After the Mosfet component arrives, the entire power system will also be tested outdoors to confirm long-term performance of charging, discharging, and delivering current to the feeder systems.

Another challenge besides not powering the system while charging is that because we have to use the battery terminals instead of the output terminals, it changes the way power is delivered when charging and could cause problems which require more testing when parts arrive. The original schematic involves connecting the Mosfet to the output terminals and not the battery terminals. Ours would connect the Mosfet to the battery terminals instead, skipping some safety features of the TP4056 charger.

## Construction

The construction process for the smart bird feeder focuses on building strong mechanical parts, preparing for electrical integration, and testing subsystems before final assembly.

Fabrication Methods and Materials Used

Most of the mechanical components for the feeder are 3D printed. Using 3D printing allows the team to quickly create parts, test different designs, and adjust as needed.

Prototyping and Final Product Construction Process

Multiple mechanical prototypes are being made to make sure all electrical components fit properly. Since the final list of electronic parts might change, the design allows extra space for possible future upgrades.

The team divided the system into smaller sections to make testing easier. Subsystems like the solar tracker, food dispensing gate, and load cell assembly are built and tested separately. Once each subsystem works correctly, they will all be combined into one complete system.

Calibration and Fine-Tuning Steps

After assembling the full system, calibration and fine-tuning will be done. The servos will be adjusted to make sure they open and close the gates correctly. The load cell will be calibrated to measure bird weights accurately. Sensor thresholds, such as light levels for opening the gate, will be adjusted based on real outdoor testing. Software fine-tuning will also happen after full system assembly to make sure that all parts work together smoothly.

## Testing and Validation – Updated

A detailed testing plan was created to verify that both subsystems and the full smart bird feeder system function correctly under expected environmental and operating conditions. The testing process includes virtual simulations, component-level testing, environmental testing, and structural validation. Each test is designed to confirm sensor functionality, control flow, hardware strength, and overall integration.

Comprehensive Testing Process

Testing is being performed on both mechanical and electrical systems. The motors, sensors, and software are tested to make sure they respond properly to different conditions. 3D printed parts are tested for correct fit, durability, and weather resistance. Electrical testing includes checking that the power system supplies enough energy and that sensor data is accurate.

Mechanical movements, waterproofing, and cooling of the electronics are also part of the testing process. The system is tested first in small parts and then as a complete unit once everything is installed.

Test Cases

Test Case 1: CAD Design and 3D Printing Test

Purpose: Confirm proper fit and alignment of all mechanical parts.
Result: Pass
Analysis: After several design iterations, all components now fit correctly in the enclosure with sufficient space for wiring and assembly.

Test Case 2: Virtual Testing with WOKWI

Purpose: Simulate circuit wiring and control logic before hardware testing.
Result: In Progress
Analysis: So far, sensor inputs and output responses were successfully tested using WOKWI. Logic errors were corrected before physical wiring began.

Test Case 3: Hands-on Component Testing

Purpose: Verify that sensors, servos, load cell, and power circuit function correctly when wired together.
Result: In Progress
Analysis: All electrical components have been wired together on a test bench. Initial tests show correct readings and output behavior. Final validation will be done after full system installation inside the enclosure.

Test Case 4: Overtemperature Prevention

Purpose: Ensure electronics remain functional in high temperatures and verify proper cooling.
Result: Pending
Analysis: The cooling system is being designed. Tests will be conducted once the cooling fan and airflow paths are added to the system.

Test Case 5: Water Resistance Test

Purpose: Check if internal components remain dry under simulated rain.
Result: Pending
Analysis: Will be performed once the final enclosure is sealed. Water strips will be used to detect leaks during spray testing.

Test Case 6: Material Sunlight Resistance

Purpose: Confirm that printed materials can withstand exposure to sunlight.
Result: Pass
Analysis: Selected materials held their shape and did not show signs of warping after prolonged exposure to sunlight.

Test Case 7: Weather Condition Testing

Purpose: Simulate real outdoor conditions such as wind and heavy rain.
Result: Pending
Analysis: Test will be performed outdoors after final system assembly.

Test Case 8: Environmental Material Testing

Purpose: Identify printing materials that are both durable and safe for animals.
Result: Pass
Analysis: PETG and lighter-colored PLA were found to be most stable in heat and non-toxic for outdoor use.

Test Case 9: Bracket Load Stability Test

Purpose: Verify the strength and stability of the bracket that supports the bird feeder.
Result: Pass (after redesign)
Analysis: In the first test, a weighted load caused the original bracket to bend, showing that it could not hold the full feeder weight. The bracket was redesigned with thicker support and stronger geometry. The updated version successfully held the full feeder weight during repeat testing.

Test Case 10: Solar Tracker and Battery System Test

Purpose: Confirm solar tracking function, relay control, and long-term battery reliability.
Result: Partial Pass
Analysis: The solar tracker was successfully programmed to reposition based on LDR sensor inputs. When one side was shaded, the servos moved the solar panel until both sensors detected sunlight again. The relay control also functioned as intended—opening in sunlight to charge and closing in shade to prevent undercharging. Long-term testing confirmed that the battery could reliably power all components. However, a limitation with the TP4056 charging module was identified: its output terminals triggered a safety limit when the system drew more than 1 amp. This was resolved by connecting the MT3608 boost converter directly to the battery terminals, which allowed it to draw the 2 amps needed for stable operation.

# Data Interpretation & Analysis

- Present and analyze the data collected during testing and project operation.
  - The data collected during the testing phases included values such as the overall mechanical measurements and how things would fit together after 3D printing, as well as circuit component compatibility and their operations defined by the code in microPython. Most components were originally based on one thing like the size of the pico and how many ports it had along with the power requirements. This lead to what kind of motors to use, the batteries, solar cell size and the relay for it, how much light triggers detection, and what weight to sense for a certain bird.
  - Raw Data:
    - Project Size: 4 inches Wide x 2 feet Tall
    - Bird Weight: 600 grams
    - Light Detection from ADC: 800
    - System Power requirements: 5V, 2 Amps
    - Charging requirements: 5V, 600 milliamps
    - Motor uses: Uln2003 driver, stepper, and 3x, 9-gram servos
    - IR Sensor Distance: 0.5 inches
- Discuss the meaning and implications of the obtained results.
  - Due to some of the results in the initial design, parts had to be redesigned in CAD to make sure they fit correctly and fixed some of the issues that occurred like the feeder bowl shape, component placement, and mechanical joints for both the lid and solar tracker. In addition, the Raspberry Pico only contained 3 analog to digital converters which forced us to use a digital light detecting resistor rather than simply using a photoresistor. This occurred again when trying to use the servo to rotate 360 degrees, because it can only move 180 degrees, meaning the uln2003 had to be implemented to work with the Raspberry Pico, driver a stepper motor. Lastly, the TP4056 charger would trigger overcurrent protection through its outputs, requiring the MT3608 to be connected directly to the lithium-ion batteries instead of through the charger’s output.
- Compare your results with theoretical expectations and existing research.
  - We expected not to get the results we were looking for in the first trials because it is difficult to do so on the first try. So constant adaptations of the project slowly developed though the month, resulting in major changes while maintaining the original idea. Online there are research documents on building similar products, however they do not fully imitate the work we wanted to do. Other feeders dispense food or have a camera, but do not offer solar rechargeability, food protection, or AI imaging assistance. Fewer others even used a Raspberry Pico on such a small scale so much of the final collected data like the physical measurements, working circuit, and code was done overtime as we figured out what worked and what didn’t.

# Conclusion

- Summarize the key findings and achievements of your project.
  - Few parts needed to be modified to work well with each other such as the physical dimensions, circuit connections, and code requirements.
  - Product size is needed to withstand the bird, other animals, contain components, and actuate without resistance.
  - Sensors must be within researched values like bird weight, light intensity, detection distances, and power requirements.
  - Power system needed to charge and discharge at proper voltages and current while also having a long working life.
- Restate the project objectives and evaluate their fulfillment.
  - The project objectives are to have a bird feeder that can dispense food to the correct bird based on weight, during the day only. It will be able to connect to Wi-Fi, track the sun, detect bird species, and sense when the bowl or the storage container is empty.
- Discuss the overall success of your project and its limitations.
  - Currently we have been very successful in creating a working product, however it is not assembled yet and still requires three more components to be implemented before its completion. The limitation for this system is feeding crows and keeping out other scavengers. With small changes in the design though, it can be used to feed other animals, charge a larger battery with MPPT, or be utilized in a factory to dispense other materials while keeping track of specific variables.

# Future Work

At this stage, the overall design remains consistent with our original plan, and that’s intentional. We’re now fully engaged in the build phase, installing components, testing circuits, and verifying mechanical movements. Tasks include wiring the load cell and stepper motor, calibrating sensor inputs, and confirming servo behavior in real-world conditions. We’ve also started 3D printing parts for the enclosure and feeder mechanism, refining each iteration for better fit and function.

On the software side, we’re moving from simulations to hardware testing. The control logic is being deployed to the Raspberry Pi Pico W, and we’re actively debugging issues with servo timing, sensor thresholds, and program flow. We’ve also implemented a private GitHub repository to streamline version control and collaboration. This gives the team a centralized place to share STL files, code, and documentation without losing progress or duplicating work. As the system comes together, we’re logging pass/fail results, updating code as needed, and preparing for full system integration and testing.

Looking ahead, there are still several features we plan to implement as time allows. These include AI assistance for species identification, a camera module, a more efficient cooling system, and an automated food level sensor. Future research will focus on expanding wireless functionality using the ESP32 platform to stream video and potentially incorporate AI analytics alongside it.

Beyond bird feeding, this project has broader applications. Every subsystem we’ve developed, from motion control to environmental sensing, could be adapted to other fields. The design could be scaled for use in industrial automation, smart agriculture, or even low-power off-grid systems. Every part of this system was designed in CAD, wired and coded by hand, and serves as proof of our ability to integrate mechanical, electrical, and software systems into a functional, responsive device.

# References

Raspberry Pi - 28BYJ-48 Stepper Motor ULN2003 Driver | Tutorials for Newbies. (n.d.). Tutorials for Newbies.

https://newbiely.com/tutorials/raspberry-pi/raspberry-pi-28byj-48-stepper-motor-uln2003-driver

Feeder.ino copy - Wokwi ESP32, STM32, Arduino Simulator. (n.d.).

https://wokwi.com/projects/429368894967044097

https://docs.arduino.cc/learn/electronics/servo-motorsLinks to an external site.

https://forum.allaboutcircuits.com/threads/charge-two-18650-using-single-tp4056.183851Links to an external site.

https://www.best-microcontroller-projects.com/tp4056.htmlLinks to an external site.

https://forum.arduino.cc/t/18650-battery-shield-operation-and-modification/688048/6Links to an external site.

https://m.youtube.com/watch?v=wMtaWqGTlP4

# Appendices

## Appendix A: Block Diagram

Block Diagram 1 - Updated

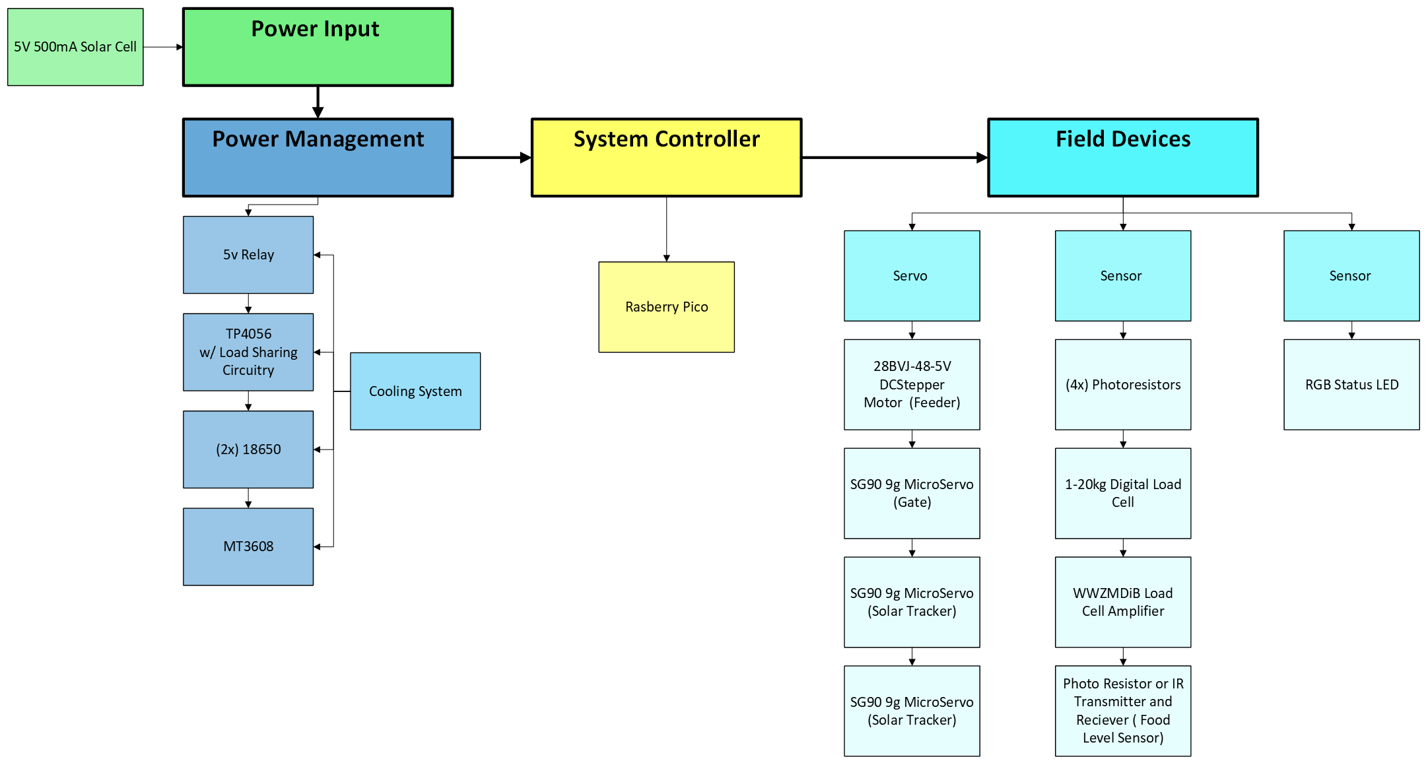
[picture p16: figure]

## Appendix B: Trade Study

Trade Study 1: Animal Identification Method (Jeffery Wheeler)

Jeffery compared three options to distinguish birds from other animals: a contact sensor, an AI model with a camera, and a load cell. After reviewing accuracy, compatibility, cost, and power needs, the load cell was selected. It offers a good balance of accuracy and low power use, fits well with the system, and can be easily integrated into the perch design.

Trade Study 2: Microcontroller Selection (Sean Copple)

Sean evaluated the Arduino Uno, Raspberry Pi Zero 2 W, and Raspberry Pi Pico W for controlling the smart bird feeder. The Raspberry Pi Pico W was selected because it has strong wireless capability, good GPIO support for sensors and motors, a small size for the case, and better power efficiency. It also allows faster software development.

Trade Study 3: Servo Motor Selection for Food Gate (Valentin Wolf)

Valentin compared three servo motors: the SG90, MG90S, and DS3218. Although the MG90S is stronger and better for outdoor use, the team already owns SG90 servos. The plan is to first test the SG90. If it does not provide enough torque, the MG90S will be used as a backup.

Trade Study 4: Boost converter selection (Josh Tilson)

Josh evaluated the boost converter to output more current for the system. His three choices were between MT3608, XL6009, and XL6019. At first the MT3608 was chosen because it was a cheaper well-known option which still works in the circuit now. However, it has a limitation of 2 amps which could be overdrawn if all components are working at the same time. It is unlikely that it will take more than 2 amps during its operation, but if more current is required the XL6019 is a good replacement that is slightly more expensive and is capable of 5 amps instead.

## Appendix C: Budget

### Budget

The Budget for this project is about 150 Dollars for the major components of the Bird feeder.

### Parts List


### Bill of Materials (BOM)

## Appendix D: Schedule/Gantt Chart

#### Team Structure:

The project team is composed of five members: Jeffery Wheeler, Sean Copple, Joshua Tilson, and Valentin Wolf. Each member brings a unique skill set to the group, allowing for a well-rounded and collaborative approach to the smart bird feeder project. Team roles were assigned based on individual experience and personal strengths.

Jeffery Wheeler is the project lead. He initially proposed the bird feeder idea and has extensive experience in mechanical systems and control design. He also owns a 3D printer and has a clear vision for the final product’s design and functionality. As the team lead, he will guide the project’s direction, coordinate tasks, and make final decisions when needed.

Sean Copple is highly skilled in both electrical and mechanical tasks and also owns a 3D printer. Sean is responsible for identifying and sourcing critical hardware components and assisting with physical assembly and wiring.

Joshua Tilson is part of the Mechatronics program and brings strong experience in building control systems. Like the rest of the group, he has access to a 3D printer and is involved in selecting components for the project. Joshua will also support hardware integration and testing.

Valentin is responsible for the documentation and communication. He is responsible for writing and organizing project materials, scheduling meetings, and coordinating information flow between team members. He also supports all other areas of the project as needed.

Although specific roles have been assigned, all team members contribute across disciplines, including software, hardware, and design. Tasks are divided to maximize efficiency and are reassigned as needed based on availability and progress. All major decisions are made collectively. If any disagreement arises, the project lead will make the final decision to maintain momentum and ensure consistency.

#### Communication Plan: - Updated

Effective communication is essential for this project, especially since the team members are located in different time zones. To stay connected and on track, the team has implemented a structured communication plan with multiple tools and channels.

A dedicated group chat was created for quick updates, sharing images and videos, and staying in regular contact. For more formal discussions, the team uses the ECPI Canvas group page, which includes discussion boards for each project topic. This platform is also used for collaboration on weekly assignments and lab reports.

In addition, the team shares and updates project files through a shared folder on the ECPI group page. All files are organized by week and labeled with clear names and timestamps to track progress and maintain version control. To improve collaboration and file management, the team also implemented a GitHub repository. GitHub became the preferred platform because it offers more storage space, better organization of files, and a more efficient way to share and manage code. It also supports version control and allows the team to work on different parts of the code simultaneously without conflicts.

Another reason for moving to GitHub is that the team plans to continue developing this project in the future. By keeping an active and well-organized repository, the project remains easy to access and ready for future improvements or feature additions beyond the current course requirements.

The team meets twice a week. The first meeting takes place at the beginning of the week to plan tasks and delegate responsibilities. A second meeting is held every Sunday to review the week’s progress, discuss any issues, and prepare for the next steps. These meetings are held virtually to accommodate different time zones.

This structured plan ensures that all team members are informed, involved, and able to contribute effectively throughout the five-week project and beyond.

#### Gantt Chart:

Gantt Chart


## Appendix E: Code

### Flowchart

Flowchart System Overview


Code:

Feeder Section -

#from hx711_gpio1 import HX711
import time
from machine import Pin,PWM

# Constants for the stepper motor pins
IN1 = Pin(18, Pin.OUT)
IN2 = Pin(19, Pin.OUT)
IN3 = Pin(20, Pin.OUT)
IN4 = Pin(21, Pin.OUT)
IRSensor = Pin(16, Pin.IN, Pin.PULL_UP)
Photosensor = machine.ADC(28)
#data_pin = Pin(14, Pin.IN, Pin.PULL_DOWN)
#clock_pin = Pin(15, Pin.OUT)
#hx711 = HX711(clock_pin, data_pin)
#hx711.tare()
lid = PWM(Pin(2))
lid.freq(50)

# Sequence for moving the stepper motor
SEQUENCE = [[1,0,0,0], [0,1,0,0], [0,0,1,0], [0,0,0,1]]

# Function to move the stepper motor
def move_stepper(direction, steps):
# Set the input pins
pins = [IN1, IN2, IN3, IN4]

# Set the direction of the sequence
if direction == 'forward':
sequence = SEQUENCE
elif direction == 'backward':
sequence = list(reversed(SEQUENCE))

# Loop through the specified number of steps
for i in range(steps):

# Set the input pins based on the current step
for j in range(len(pins)):
pins[j].value(sequence[i%4][j])

# Delay between steps
time.sleep(0.002)

# Main loop
while True:
print(IRSensor.value())
print("ADC: ", Photosensor.read_u16())
#raw_wt = hx711.read()
#sf = 340/350000
#weight = raw_wt*sf

if (IRSensor.value() == 0 and Photosensor.read_u16() <= 800): # if bowl is empty (IR) and is daytime(photosensor)
move_stepper('forward', 512)
time.sleep(2)

if (weight.value() <= 600 and Photosensor.read_u16() <= 800): # if weight is in range and is daytime
for position in range(500000, 2500000, 5000): # open lid
lid.duty_ns(position)
time.sleep(0.01)

else:
for position in range(2500000, 500000, -5000): # close lid
lid.duty_ns(position)
time.sleep(0.01)

Solar Tracker Section -

import time
from machine import Pin,PWM
#Looking at the panel with sensors facing you
TL = Pin(3, Pin.IN) #LDR top left
TR = Pin(4, Pin.IN) #LDR top right
BL = Pin(5, Pin.IN) #LDR Bottom left
BR = Pin(6, Pin.IN) #ldr Bottom right

Xaxis = PWM(Pin(2)) # sets x and y axis servo pins as pwm signal
Yaxis = PWM(Pin(17))

Xaxis.freq(50) # sets x and y axis pwm output frequency
Yaxis.freq(50)

positionx = 1500000 # start each servo to their midpoint position in nanseconds as duty cycle
positiony = 1500000

while True: # loop section

if (TL.value() == 1 and TR.value() == 1): #if top left and top right LDR sensors reach their preset values
Yaxis.duty_ns(positiony) # move y axis servo to saved variable
positiony = positiony + 5000 # add 5000 nanoseconds to duty cycle and change the variable value
time.sleep(0.01) # wait 10 milliseconds between each step

if (TL.value() == 1 and BL.value() == 1): # same sequences as before with different sensors sets
Xaxis.duty_ns(positionx)
positionx = positionx - 5000 # negative indicates reverse direction
time.sleep(0.01)

if (BL.value() == 1 and BR.value() == 1):
Yaxis.duty_ns(positiony)
positiony = positiony - 5000
time.sleep(0.01)

if (TR.value() == 1 and BR.value() == 1):
Xaxis.duty_ns(positionx)
positionx = positionx + 5000
time.sleep(0.01)

## Appendix F: Wiring Diagrams/Parts Design

Wiring and Parts for System


Solar Load Sharing

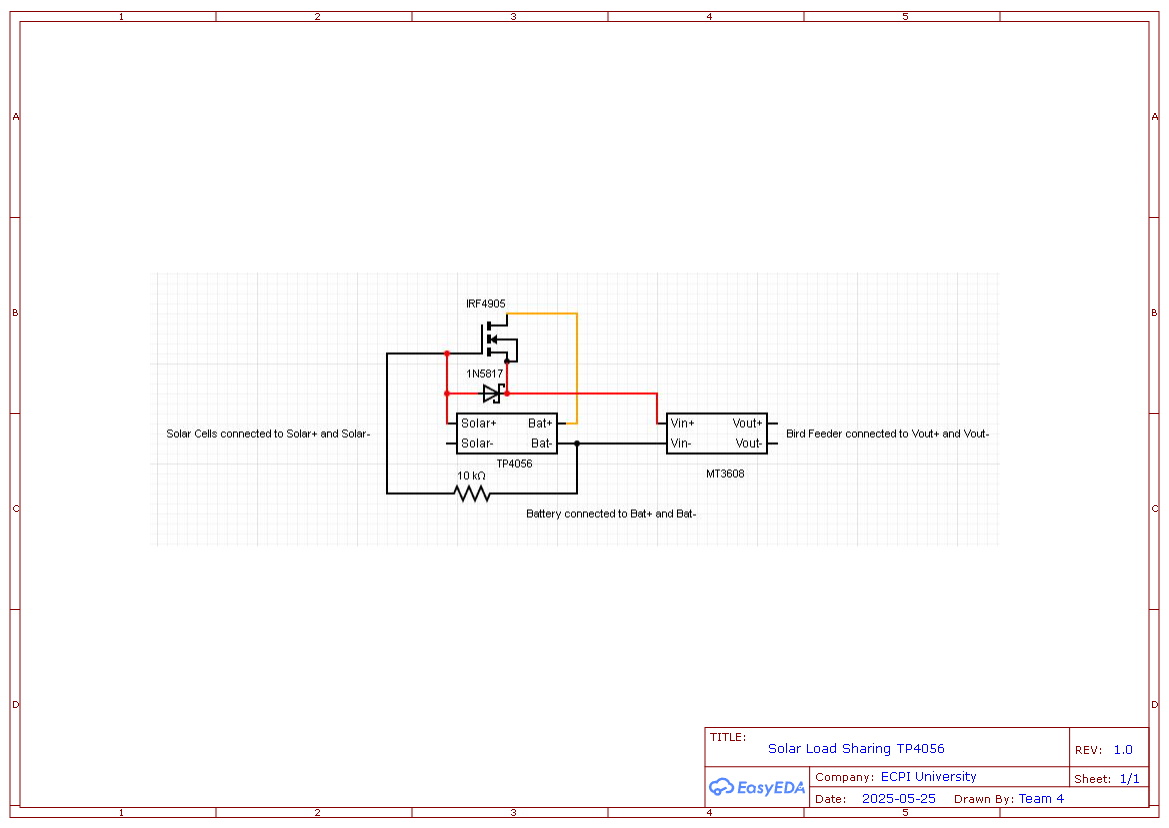
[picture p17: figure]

School of Engineering Technology

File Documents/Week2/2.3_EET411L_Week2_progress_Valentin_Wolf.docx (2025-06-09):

# Progress Report

Week 2 | | | 5/25/2025
Group Members | | Jeffery Wheeler
| | Joshua Tilson
| | Sean Copple
| | Valentin Wolf
Project Title | | The Smart Bird Feeder

## Task: Mechanical Prototype Assembly

Task Status: In Progress | | | 90% Completed: | | | Jeffery Wheeler
Task Details

Completed full 3D print of version 1 feeder housing. All parts were assembled to test physical fit of electrical components. Next step is to perform functional testing with electronics installed.

Modifications were made to the bracket that holds the bird feeder. The new version is able to hold more weight.

A change was made to the mechanical design to allow easy access to a USB cable. This change makes it easier to access for program updates
Conclusions

All mechanical parts fit correctly, and layout is confirmed. Further testing is required to check motion, access, and cable routing before finalizing version 2 design.
Action items | | | | | Person responsible | | Deadline
Begin full system testing inside housing | | | | | Jeffery Wheeler | | 6/01/2025
Prepare feedback on version 1 for version 2 improvements | | | | | Jeffery Wheeler | | 6/01/2025

Task: Component Integration Testing
Task Status: In Progress | | | 70% Completed: | | | Joshua Tilson
Task Details

All sensors and motor components were connected on a test bench. Ongoing tests are running to confirm proper integration between power supply, load cell, servo, and sensors.

All major components function in initial test setup.
Conclusions

Initial integration looks good. Power and sensor response are stable. Some minor adjustments to wiring and code structure are expected as testing continues.
Action items | | | | | Person responsible | | Deadline
Finish component testing with all sensors active | | | | | Joshua Tilson | | 6/01/2025
Log any errors or unexpected behaviors during tests | | | | | Joshua Tilson | | 6/01/2025

## Task: Sensor Fault Detection Code

Task Status: In Progress | | | 40% Completed: | | | Valentin Wolf
Task Details | Construction of prototype version 1

Code is being written to detect faulty sensor conditions. For example, photoresistors or IR sensors that do not change state when expected (e.g., stuck high or low).
Conclusions

Basic structure for fault detection is in progress. More cases and triggers will be added after additional testing and input from component integration.
Action items | | | | | Person responsible | | Deadline
Add logic to handle sensor timeout or stuck states | | | | | Valentin Wolf | | 6/01/2025
Test error handling responses in Wokwi or on real hardware | | | | | Valentin Wolf | | 6/01/2025

## Task: GitHub Code & File Sharing Setup

Task Status: In Progress | | | 100% Completed: | | | Sean Copple
Task Details

Created a new shared GitHub repository to improve team collaboration. Includes release notes, shared code access, and expanded storage for print files.

Github was updated and all team members were trained on how to use the platform effectively
Conclusions

The new system allows real-time updates and easier code review. It also supports file versioning and notes to reduce confusion and track changes.

The new platform shows great improvement in communication.
Action items | | | | | Person responsible | | Deadline
Share login and usage instructions with team | | | | | Sean Copple | | 5/31/2025
Use GitHub for all future code versions and STL file uploads | | | | | Sean Copple | | 5/31/2025

## Task: Solar Tracking System

Task Status: In Progress | | 70% Completed: | | Joshua Tilson
Task Details

Assemble and test the solar tracking system using light-dependent resistors (LDRs) and servo motors. The parts are currently being 3D printed and put together to check boundaries, avoid collisions, and ensure the solar panel adjusts its position based on actual sunlight. Final testing will be done outdoors.
Conclusions

Initial movement testing has been successful. Further testing with real sunlight is needed to confirm tracking accuracy. Once the Mosfet arrives, full system testing with charging and current delivery will be completed.
Action items | | | Person responsible | | Deadline
Test solar tracker movement with sunlight | | | Joshua Tilson | | 6/01/2025
Install and test Mosfet for charging circuit | | | Joshua Tilson | | 6/01/2025

## Task: Testing and Validation

| Task Status: In Progress | | 60% Completed: | | Valentin Wolf
| Task Details

Created the Testing and Validation section for the project report. This included developing a test plan for each subsystem, writing test case descriptions, pass/fail results, and brief analysis of each outcome. Real testing input from team members was reviewed and integrated into the documentation.
| Conclusions

The testing tasks have been defined and the testing is in progress.
| Action items | | | Person responsible | | Deadline
| Complete all tests and report results | | | Valentin Wolf | | 6/01/2025

## Task:

Task Status: In Progress | | | 70% Completed: | | Personel
Task Details
Conclusions
Action items | | | | Person responsible | | Deadline
| | | | | | 6/01/2025

School of Technology 2025

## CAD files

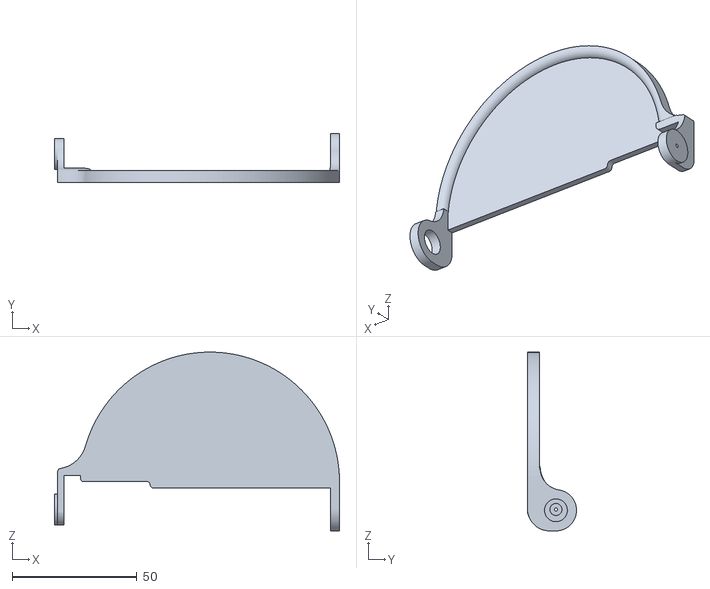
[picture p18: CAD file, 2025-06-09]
STL_Models/Test Lid.stl
114.3 x 19.7 x 71.7

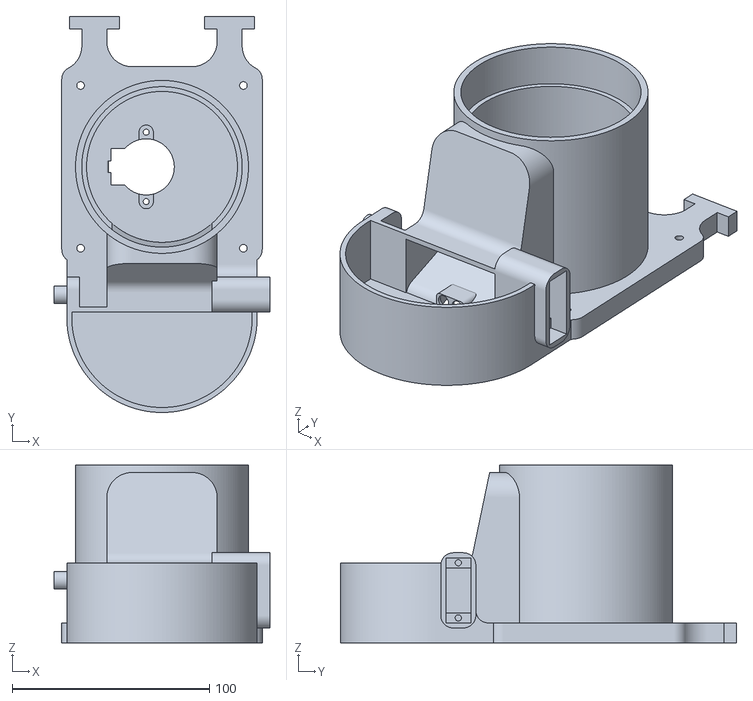
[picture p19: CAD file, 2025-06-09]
STL_Models/Feeder Base 2.0.stl
109.2 x 200.7 x 90.2

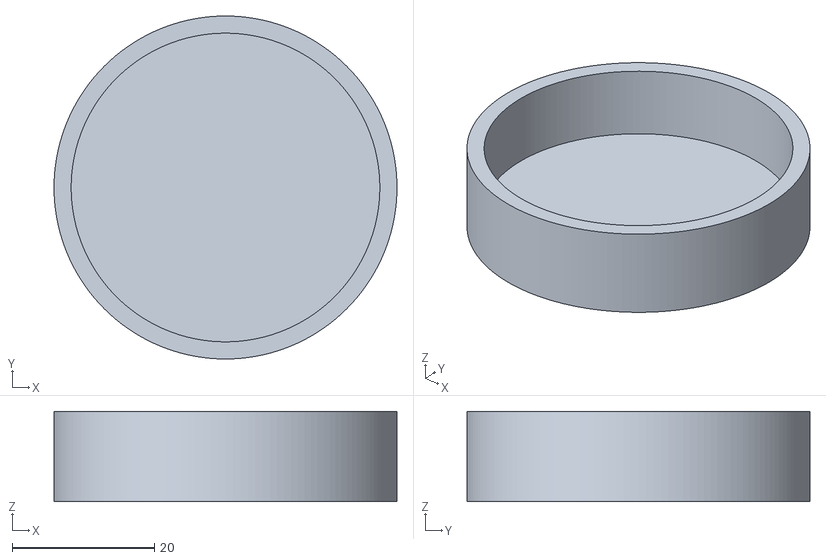
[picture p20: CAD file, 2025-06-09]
STL_Models/Feeder Cap.stl
48.3 x 48.3 x 12.7

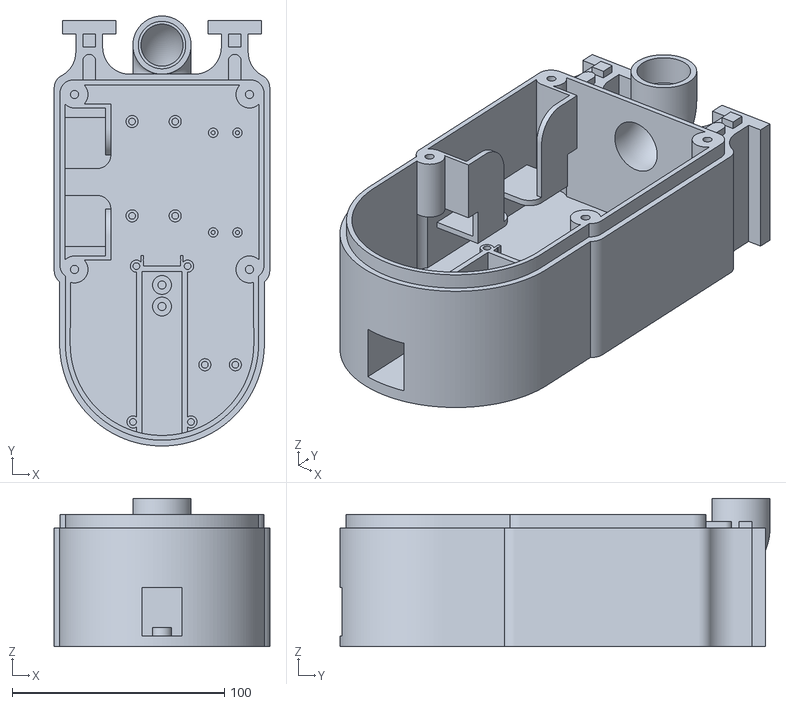
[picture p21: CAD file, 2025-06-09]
STL_Models/Feeder Component Box 2.0.stl
101.6 x 202.7 x 69.8

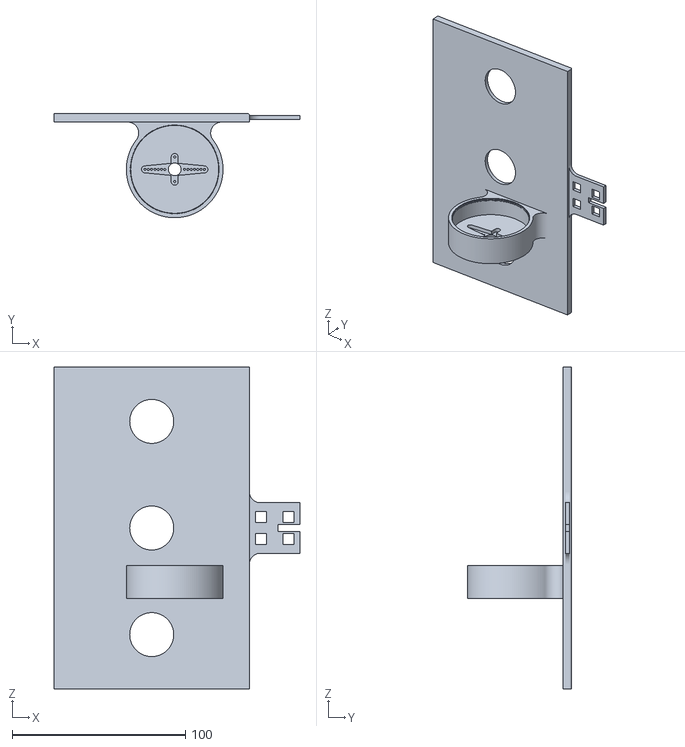
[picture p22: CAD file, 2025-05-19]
STL_Models/Solar Panel Tray.stl
142.1 x 60.3 x 186.1

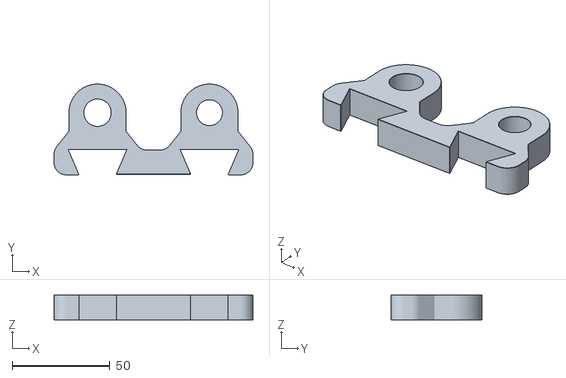
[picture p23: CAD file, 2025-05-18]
STL_Models/Mount Latch.stl
101.6 x 46.4 x 12.7

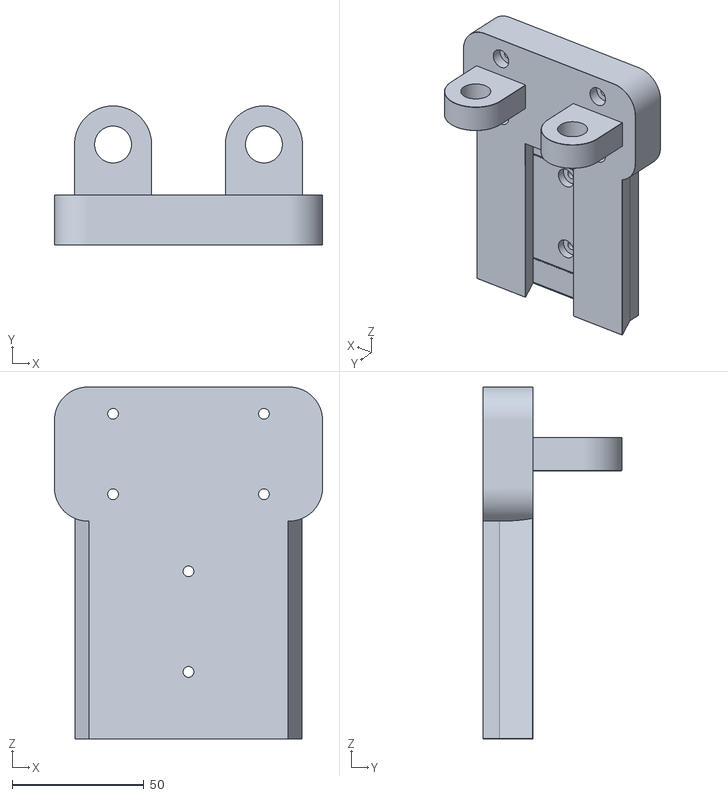
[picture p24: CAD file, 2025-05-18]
STL_Models/Feeder Mount.stl
101.6 x 52.7 x 133.4

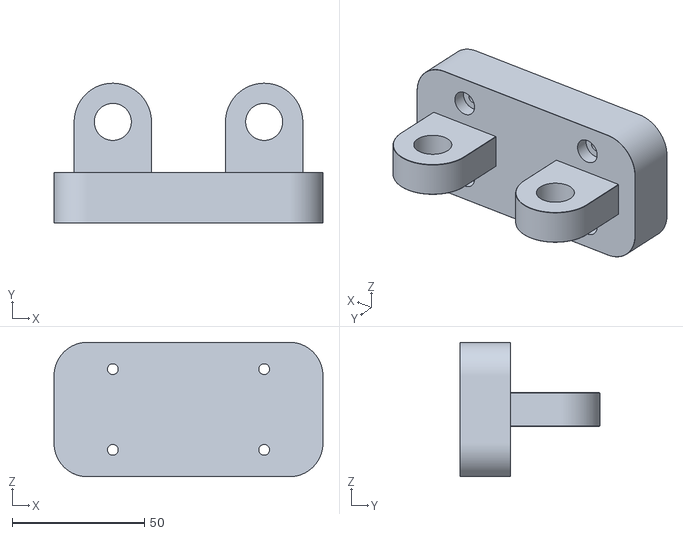
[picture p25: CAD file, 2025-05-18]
STL_Models/Feeder Top Mount.stl
101.6 x 52.7 x 50.8

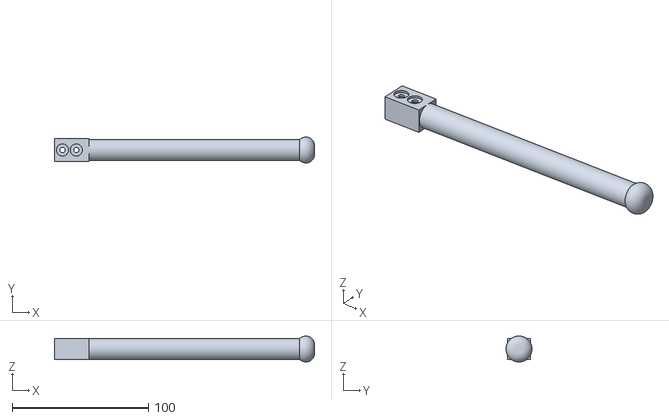
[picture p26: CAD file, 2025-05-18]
STL_Models/Perch.stl
190.5 x 19.0 x 19.0

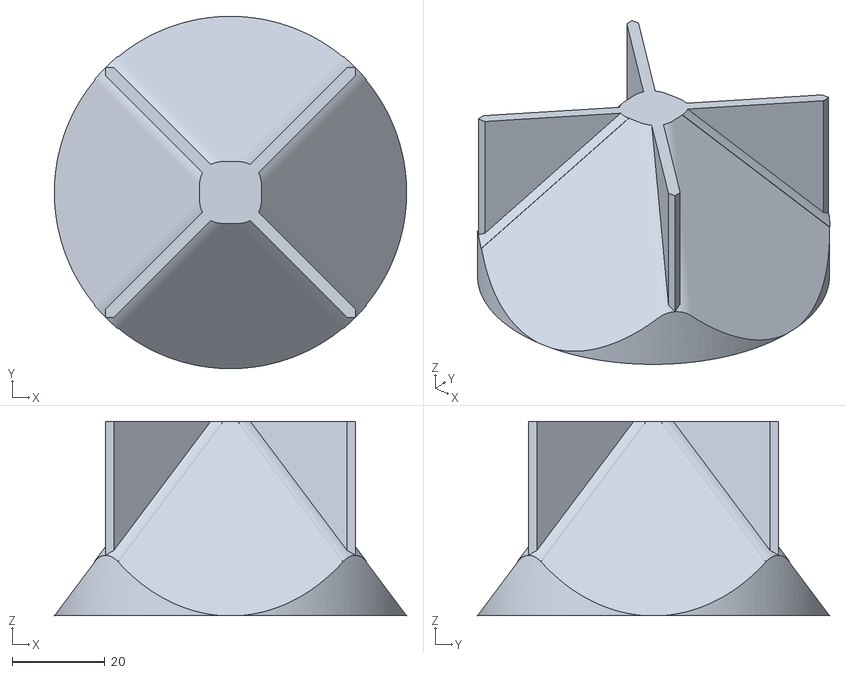
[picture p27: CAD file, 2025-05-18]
STL_Models/Feeder Wheel.stl
75.9 x 75.9 x 41.9

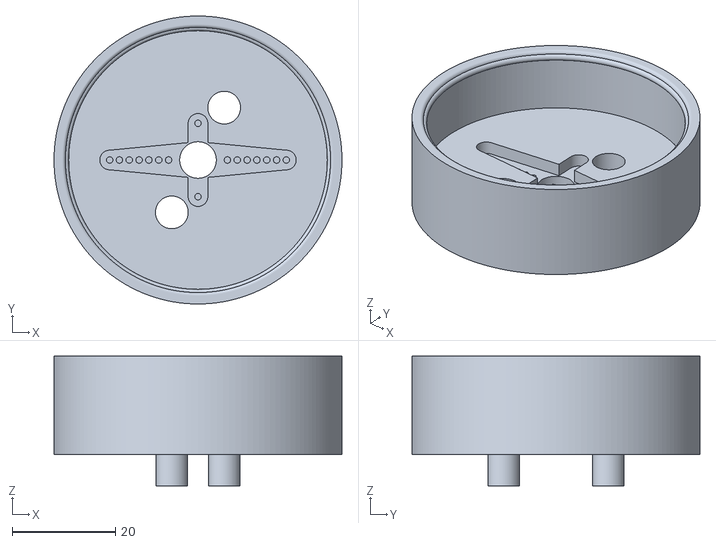
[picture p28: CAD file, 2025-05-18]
STL_Models/Solar Mount Base.stl
55.9 x 55.9 x 25.1

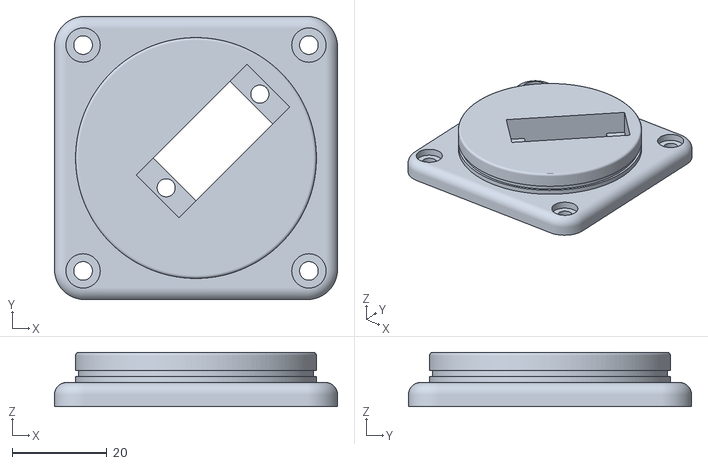
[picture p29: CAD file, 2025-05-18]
STL_Models/Solar Roof Mount.stl
59.7 x 59.7 x 11.4

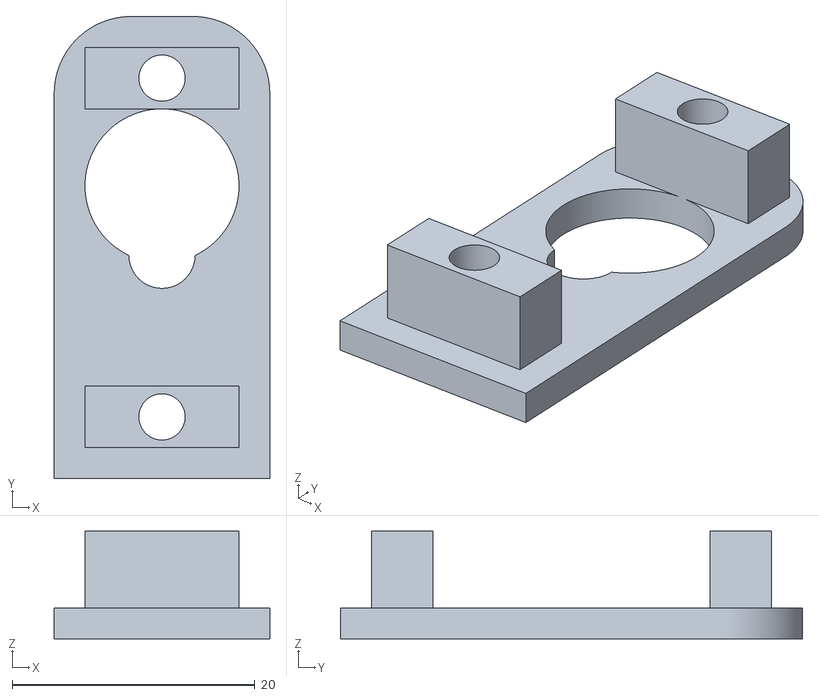
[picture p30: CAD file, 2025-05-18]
STL_Models/Feeder Base Servo Plug.stl
17.8 x 38.1 x 8.89

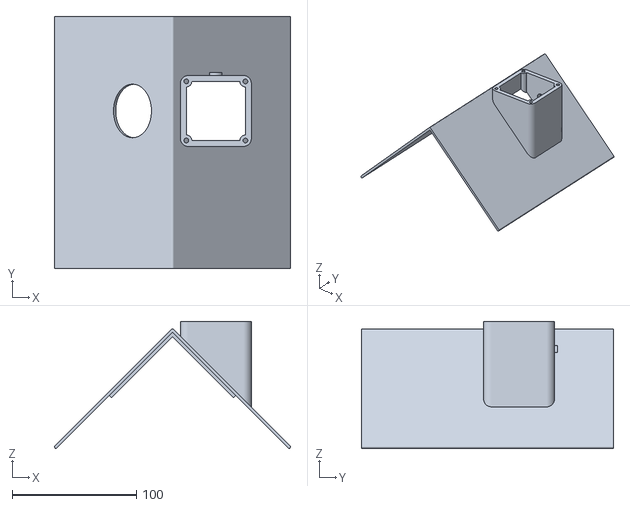
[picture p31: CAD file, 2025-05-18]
STL_Models/Feeder Roof.stl
190.1 x 203.2 x 102.5

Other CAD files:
STL_Models/Wire Tube.stl
STL_Models/Light Sensor Mount.stl
STL_Models/Half Solar Mount No Servo.stl
STL_Models/Feeder Load Sensor Cover.stl
STL_Models/Feeder Roof Base.stl
STL_Models/Half Solar Mount With Servo.stl
STL_Models/Stepper plug.stl
STL_Models/Wheel Spacer.stl

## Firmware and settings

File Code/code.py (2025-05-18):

import time
from machine import Pin, PWM, ADC

class SolarTracker:
    def __init__(self):
        # Initialize LDR sensors
        self.TL = Pin(3, Pin.IN)  # Top Left
        self.TR = Pin(4, Pin.IN)  # Top Right
        self.BL = Pin(5, Pin.IN)  # Bottom Left
        self.BR = Pin(6, Pin.IN)  # Bottom Right
        
        # Initialize axis servos
        self.Xaxis = PWM(Pin(2))
        self.Yaxis = PWM(Pin(17))
        
        # Set PWM frequency
        self.Xaxis.freq(50)
        self.Yaxis.freq(50)
        
        # Initialize positions
        self.positionx = 1500000  # Start at midpoint in nanoseconds
        self.positiony = 1500000
        
        # Initialize stepper motor pins
        self.IN1 = Pin(18, Pin.OUT)
        self.IN2 = Pin(19, Pin.OUT)
        self.IN3 = Pin(20, Pin.OUT)
        self.IN4 = Pin(21, Pin.OUT)
        self.IRSensor = Pin(16, Pin.IN, Pin.PULL_UP)
        self.Photosensor = ADC(28)
        self.lid = PWM(Pin(2))
        self.lid.freq(50)
        
        # Stepper motor sequence
        self.SEQUENCE = [[1,0,0,0], [0,1,0,0], [0,0,1,0], [0,0,0,1]]

    def move_servo(self, axis, direction):
        """Move servo in specified direction"""
        if axis == 'x':
            servo = self.Xaxis
            position = self.positionx
        else:
            servo = self.Yaxis
            position = self.positiony
            
        position += direction * 5000  # 5000ns step size
        servo.duty_ns(position)
        time.sleep(0.01)
        
        # Update position
        if axis == 'x':
            self.positionx = position
        else:
            self.positiony = position

    def move_stepper(self, direction, steps):
        """Move stepper motor in specified direction"""
        pins = [self.IN1, self.IN2, self.IN3, self.IN4]
        sequence = self.SEQUENCE if direction == 'forward' else list(reversed(self.SEQUENCE))
        
        for _ in range(steps):
            for j in range(len(pins)):
                pins[j].value(sequence[_ % 4][j])
            time.sleep(0.002)

    def control_lid(self, open=True):
        """Control lid position"""
        start = 500000 if open else 2500000
        end = 2500000 if open else 500000
        step = 5000 if open else -5000
        
        for position in range(start, end, step):
            self.lid.duty_ns(position)
            time.sleep(0.01)

    def check_sensors(self):
        """Check sensor values and return status"""
        return {
            'ir': self.IRSensor.value(),
            'photo': self.Photosensor.read_u16()
        }

    def run(self):
        """Main control loop"""
        while True:
            # Check LDR sensors for solar tracking
            if self.TL.value() == 1 and self.TR.value() == 1:
                self.move_servo('y', 1)  # Move up
            
            if self.TL.value() == 1 and self.BL.value() == 1:
                self.move_servo('x', -1)  # Move left
            
            if self.BL.value() == 1 and self.BR.value() == 1:
                self.move_servo('y', -1)  # Move down
            
            if self.TR.value() == 1 and self.BR.value() == 1:
                self.move_servo('x', 1)  # Move right

            # Check sensors for lid control
            sensors = self.check_sensors()
            print(f"IR: {sensors['ir']}, Photo: {sensors['photo']}")
            
            if sensors['ir'] == 0 and sensors['photo'] <= 800:
                self.move_stepper('forward', 512)
                time.sleep(2)
            
            # Lid control based on photosensor
            if sensors['photo'] <= 800:
                self.control_lid(open=True)
            else:
                self.control_lid(open=False)

# Create and run the solar tracker
if __name__ == "__main__":
    tracker = SolarTracker()
    tracker.run()

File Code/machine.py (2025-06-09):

# machine.py – Mocked for Codespaces testing

class Pin:
    IN = 0
    OUT = 1
    PULL_UP = 2

    def __init__(self, pin, mode, pull=None):
        self.pin = pin
        self.mode = mode
        self.state = 0

    def value(self, val=None):
        if val is None:
            return self.state  # simulate read
        else:
            self.state = val
            print(f"[MOCK] Pin {self.pin} set to {val}")

    def low(self):
        self.state = 0
        print(f"[MOCK] Pin {self.pin} LOW")

    def high(self):
        self.state = 1
        print(f"[MOCK] Pin {self.pin} HIGH")


class PWM:
    def __init__(self, pin):
        self.pin = pin
        self.freq_val = None
        print(f"[MOCK] PWM initialized on pin {pin}")

    def freq(self, hz):
        self.freq_val = hz
        print(f"[MOCK] PWM pin {self.pin} frequency set to {hz}Hz")

    def duty_u16(self, val):
        print(f"[MOCK] PWM pin {self.pin} duty set to {val}/65535")

    def duty_ns(self, val):
        print(f"[MOCK] PWM pin {self.pin} duty set to {val}ns")


class ADC:
    def __init__(self, pin):
        self.pin = pin

    def read_u16(self):
        return 700  # Simulate light level or analog input

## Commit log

2025-05-18 Create Folder for STL Files
    [Feederwheel.stl]
2025-05-18 Organized files into folders
    [Feeder Base Servo Plug.stl, Feeder Base Stepper Wheel.stl, Feeder Component Box.stl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]
2025-05-18 Renamed stl_Files to STL_Models
    [Feeder Base Servo Plug.stl, Feeder Base Stepper Wheel.stl, Feeder Component Box.stl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]
2025-05-18 Added .gitkeep to track Week folders
2025-05-19 Rename Solar Panel Tray.stl to delete
2025-05-19 Rename Solar Panel Tray.stl to delete1
2025-05-25 Rename Feeder Base Stepper Wheel.stl to Delete
2025-05-25 Rename Feeder Component Box.stl to Deleted
    [Feeder Component Box.stl]
2025-05-25 Convert pseudo code to .py files
    Created and uploaded standalone MicroPython scripts (solar_tracker.py, feeder_control.py, and ultrasonic_check.py) based on the original Word document. Each script represents a distinct hardware func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
    Please verify, make changes as needed, and notate any updates in future commits.
2025-06-02 Update solar_tracker.py
    Added boundaries for solar tracker servos
2025-06-09 Add Week 4 PowerPoint presentation
2025-06-09 Create Complete Pico MicroPython
2025-06-09 Update Week 4 PowerPoint presentation with voice
2025-06-15 Add Week 5 PowerPoint presentation
2025-06-15 Add Py_Test_HX711.py with HX711 load cell and sensor code
